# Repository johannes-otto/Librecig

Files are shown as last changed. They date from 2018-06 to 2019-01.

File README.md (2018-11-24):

# Librecig
Want to vape hard? Want to vape free?

## Disclaimer
Neither I nor any of the contributors of this project are reponsible for anything that might happen to you with self build mods. Lithium-Ion batteries are dangerous when handled incorrectly and can seriously harm you. If you build one of these mods, you take the responsibility for yourself. Also I'm not an electrical engineer. My designs work for me, but that doesn't mean that they are safe in any way.

## Please don't sell these designs
All this stuff is released under GPL V3.It should be free for anyone wanting to build his own mod.

## What this is about
I started my first build due to paranoia of the European TPD laws. I have a certain style of vaping and I don't want the government to tell me what to vape and what not.
Also I was annoyed that my favorite mods break after a year or two of constant usage and that I can't buy spare parts to repair them.

Since then building and 3D printing mods has become a passion of mine. I did countless iterations and now I think the designs reached
enough maturity to be released.That doesn't mean that this is the end. I'm constantly improving my designs and from time to time I try something completely new.
The plan is to share everything.
I hope that other modders are willing to contribute, so that we could build a free repository of mods for "Maker-Vapers".

## Available Models

- [Ratte Platform](https://github.com/johannes-otto/Librecig/blob/master/Ratte%20and%20Variations/Readme.md)
  - [Ratte](https://github.com/johannes-otto/Librecig/blob/master/Ratte%20and%20Variations/Ratte/Readme.md)
  - [Leviathan](https://github.com/johannes-otto/Librecig/blob/master/Ratte%20and%20Variations/Leviatan/Readme.md)
  - [Wisent](https://github.com/johannes-otto/Librecig/blob/master/Ratte%20and%20Variations/Wisent/Readme.md)
- [Eichörnchen](https://github.com/johannes-otto/Librecig/blob/master/Eichh%C3%B6rnchen/README.md)

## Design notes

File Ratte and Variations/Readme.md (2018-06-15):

# Ratte Base
The goal with this series of Mods is to build a versatile, easy to assemble mod. It's supposed to be easily printable, even on cheap printers.

Currently this platform offers the following battery configurations:
- 2x 18650 -> [Die Ratte](https://github.com/johannes-otto/Librecig/blob/master/Ratte%20and%20Variations/Ratte/Readme.md)
- 4x 18650 -> [Der Leviathan](https://github.com/johannes-otto/Librecig/blob/master/Ratte%20and%20Variations/Leviatan/Readme.md)
- 6x 18650 ->  [Der Wisent](https://github.com/johannes-otto/Librecig/blob/master/Ratte%20and%20Variations/Wisent/Readme.md)

The Front Panel is variable, too. You can choose between the following electronics:
- BigAl's ANT 6s
- BigAl's iPWM 6s
- A simple VM+Mosfet with a Master switch (If you're on the cheap)

New electronics might be added as I use them. But you can easily redesign a front panel for a specific board. For example a Yihi SX350 works. But you have to keep in mind that regulated boards are boring ;-).

The Side Panel is slideable, although I nearly only squonk, you can choose between the following panels:
- Blank for your Tanks/normal Drippers
- Squonk
- Top-Feed (As with the DripEZ -> The concept works way better than you might think)

## Want to build it?
[Print instructions](https://github.com/johannes-otto/Librecig/blob/master/Ratte%20and%20Variations/doc/instructions/printing.md)

[Build instructions](https://github.com/johannes-otto/Librecig/blob/master/Ratte%20and%20Variations/doc/instructions/building.md)

[Usage instructions](https://github.com/johannes-otto/Librecig/blob/master/Ratte%20and%20Variations/doc/instructions/usage.md)

[Back to main](https://github.com/johannes-otto/Librecig/blob/master/README.md)


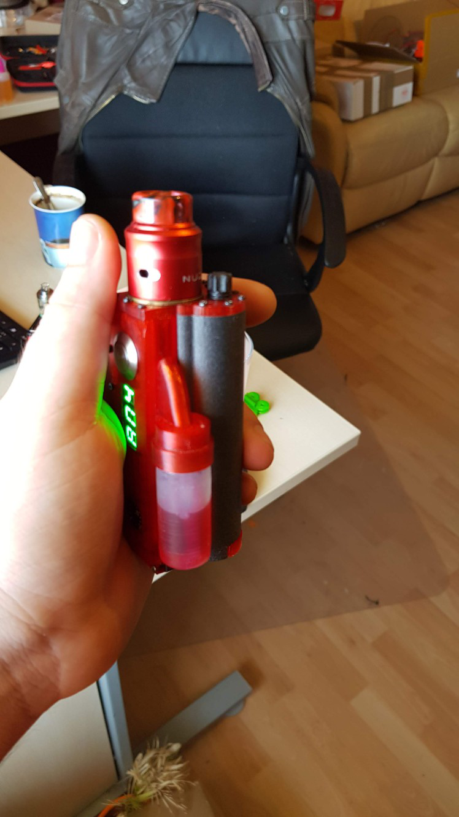
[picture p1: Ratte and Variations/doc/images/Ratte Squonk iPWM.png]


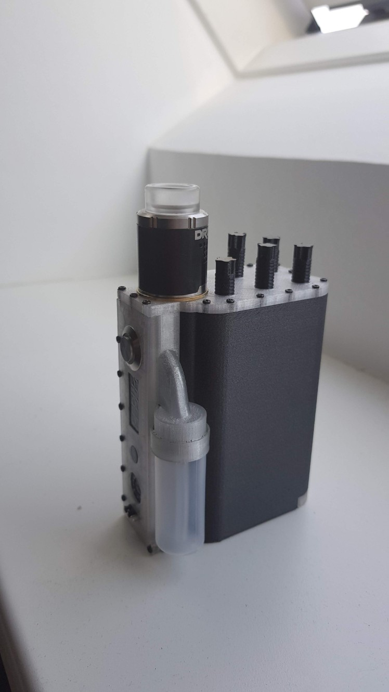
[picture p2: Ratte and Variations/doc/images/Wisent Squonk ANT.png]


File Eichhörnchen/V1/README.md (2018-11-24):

# Eichörnchen
This mod is a redesign from scratch based on the ideas and experiences of "die Ratte". The mod is pretty compact and uses 21700s. 
The exchangeable side panels have been dropped since I found myself squonking all the time anyway. I might design a non-squonk variation
at some point if I come across a tank that really blows me away.
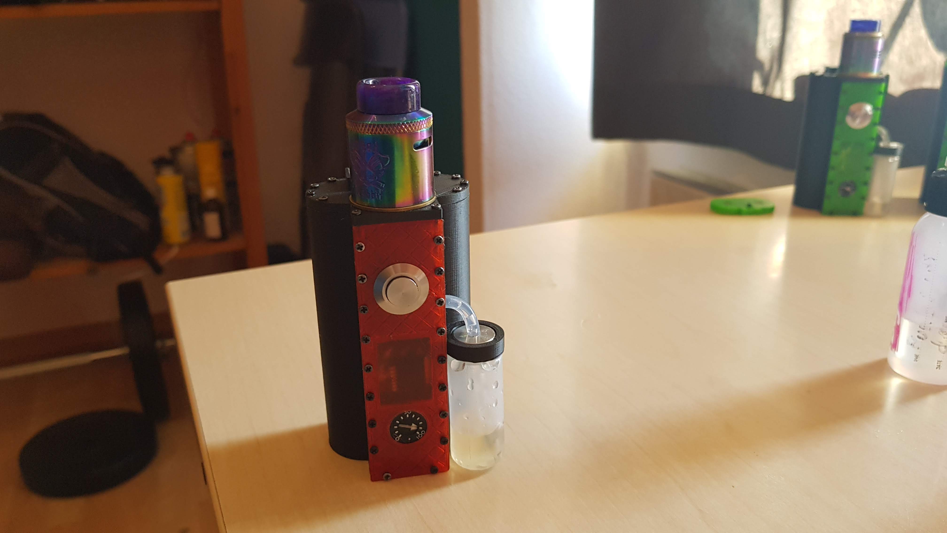
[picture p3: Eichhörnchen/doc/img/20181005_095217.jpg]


## Parts you need
- Obviously the printed parts. I recommend to use PETG
- 25mm Squonk 510 ([MM150](http://www.modmaker.co.uk/Mod-Making-Supplies/Squonk-Parts/MM510-Squonker-Connector))
- [BigAls iPWM](http://www.bigalsmods.com/Big-Als-Intelligent-PWM-iPWM-2s-6s-wpot_p_12.html)
- Squonk bottle, the design is made for the squonk bottle by [ModMaker](http://www.modmaker.co.uk/Mod-Making-Supplies/Squonk-Parts/MM-Squonker-Bottle-Kit). You can use others, but the mod is designed to fit this. If you want to use another, open an issue here and I will alter the design for you.
- Some extra tubing - about 5cm from the top of the bottle to the 510
- Mitec Switch 12mm
- 0.28" Voltmeter
- 2x M3 screws with nuts for the bottom contact bridge
- A piece of brass or copper for the bottom contact bridge
- Tiny Screws I use [Din 1.5x6](https://minischrauben.com/blech-holzschrauben-linsenkopf--44900.html). You can use others. The holes are 1.5mm x 6mm
- [Keystone 209](http://www.modmaker.co.uk/Keystone-209-Battery-Contact-Clips-x-4?search=keystone) Clips for the top contacts

## Tips and Tricks
- Put a strip of Tesa on the top of the voltmeter. It acts as a screen protector and helps to seal it.
- Cut down the legs of the switch. They don't need to be that long and may contact the 510 otherwise.
- Wait for the glue to be really dry ;-)
- Don't use overly thick cables, you don't have much extra space. I use 1.5mm²
- Don't use too long cables or it might not fit

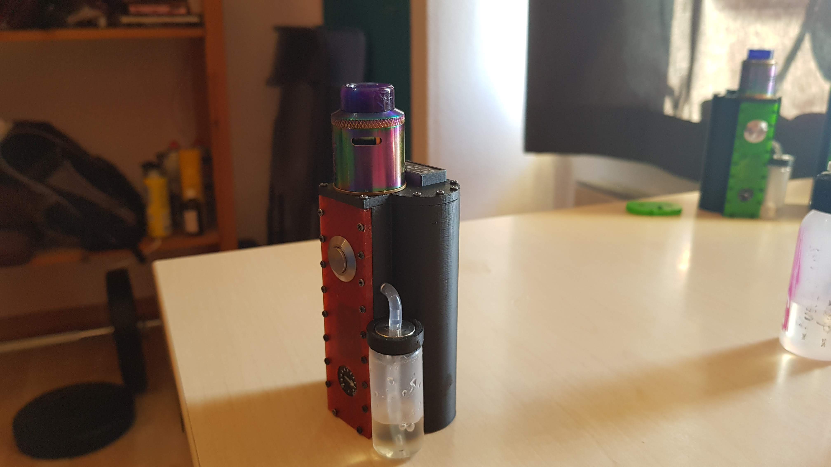
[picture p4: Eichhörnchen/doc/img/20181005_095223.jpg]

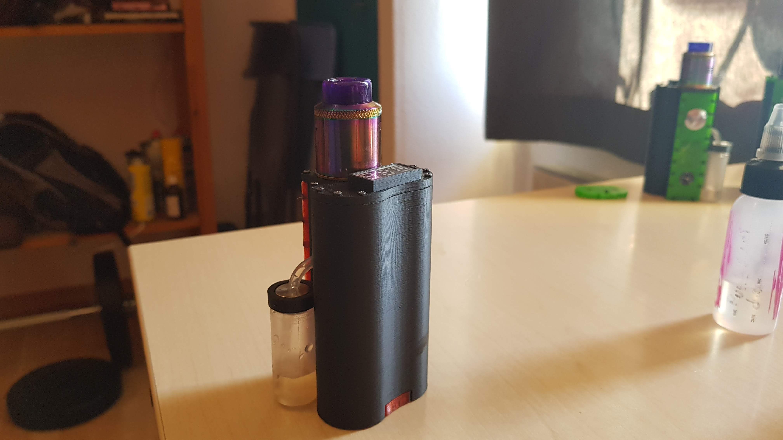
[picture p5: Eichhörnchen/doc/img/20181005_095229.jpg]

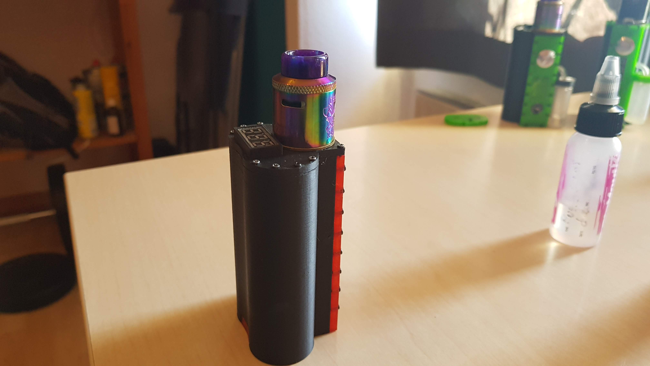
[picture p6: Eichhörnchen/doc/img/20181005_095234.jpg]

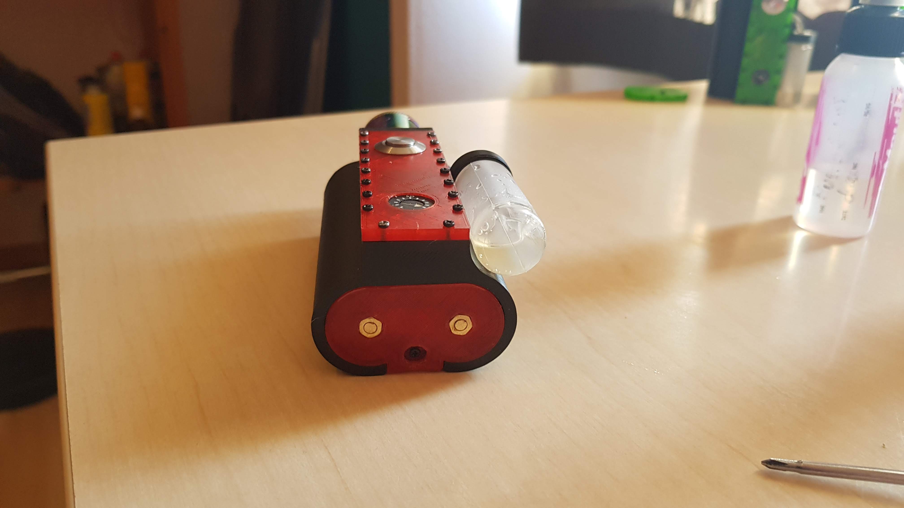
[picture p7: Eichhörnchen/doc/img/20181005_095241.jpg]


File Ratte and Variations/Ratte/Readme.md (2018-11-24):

# Die Ratte
This is a dual 18650 Mod. It's not too big, has enough battery life for a day and hits good.

[build instructions](https://github.com/johannes-otto/Librecig/blob/master/Ratte%20and%20Variations/doc/instructions/building.md)



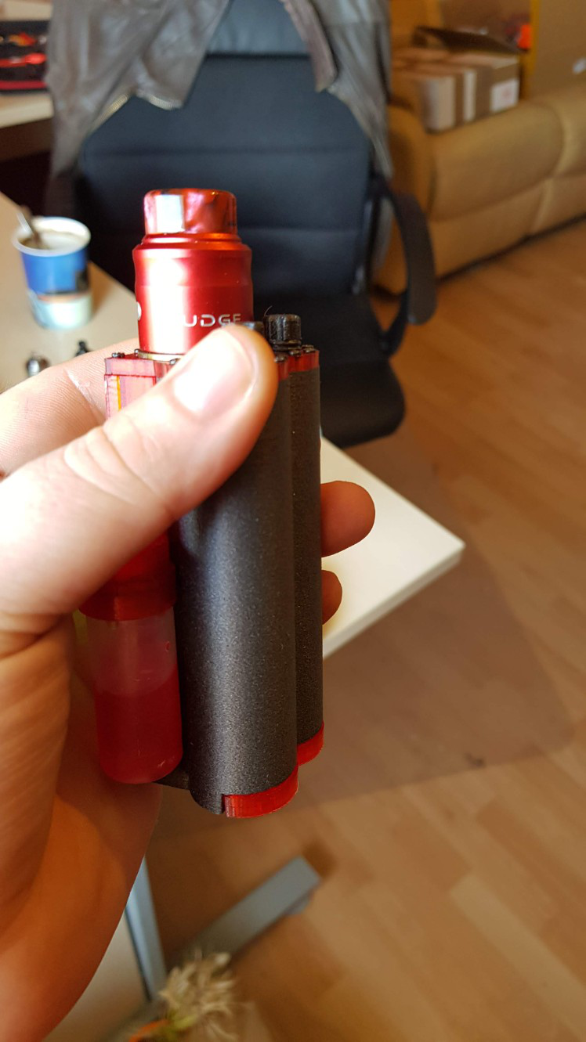
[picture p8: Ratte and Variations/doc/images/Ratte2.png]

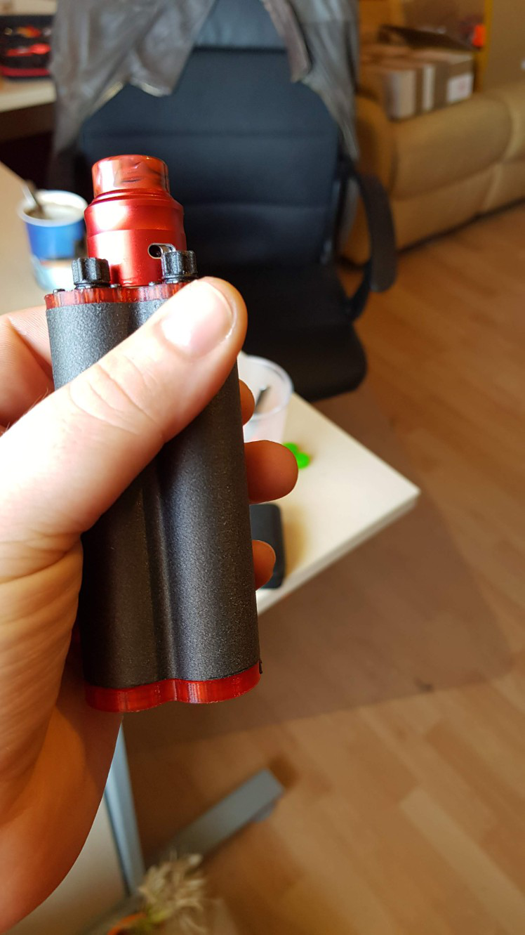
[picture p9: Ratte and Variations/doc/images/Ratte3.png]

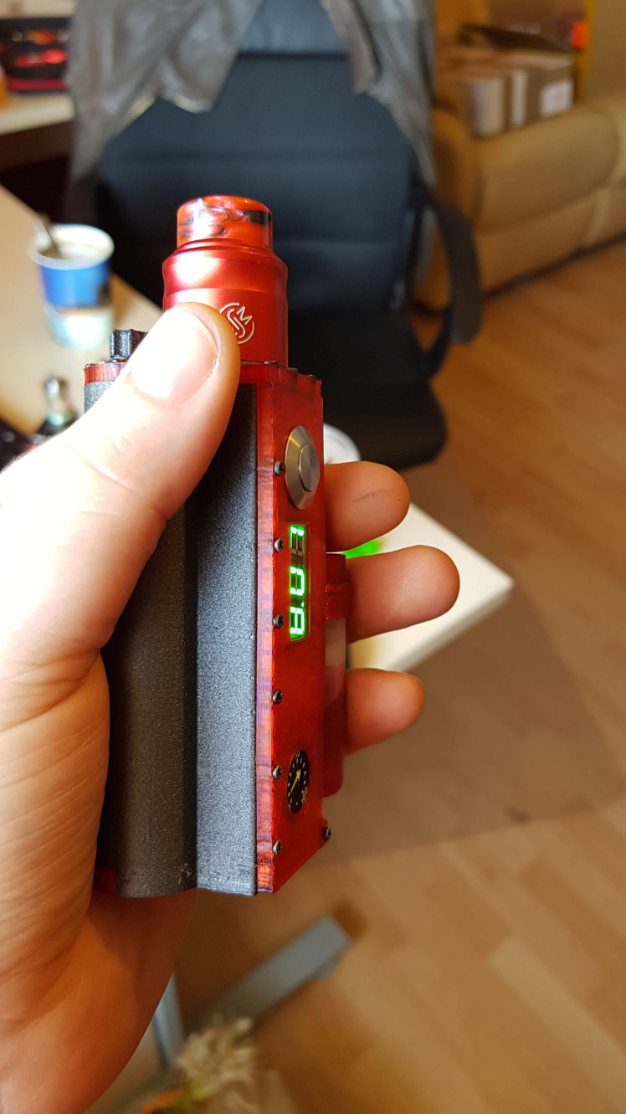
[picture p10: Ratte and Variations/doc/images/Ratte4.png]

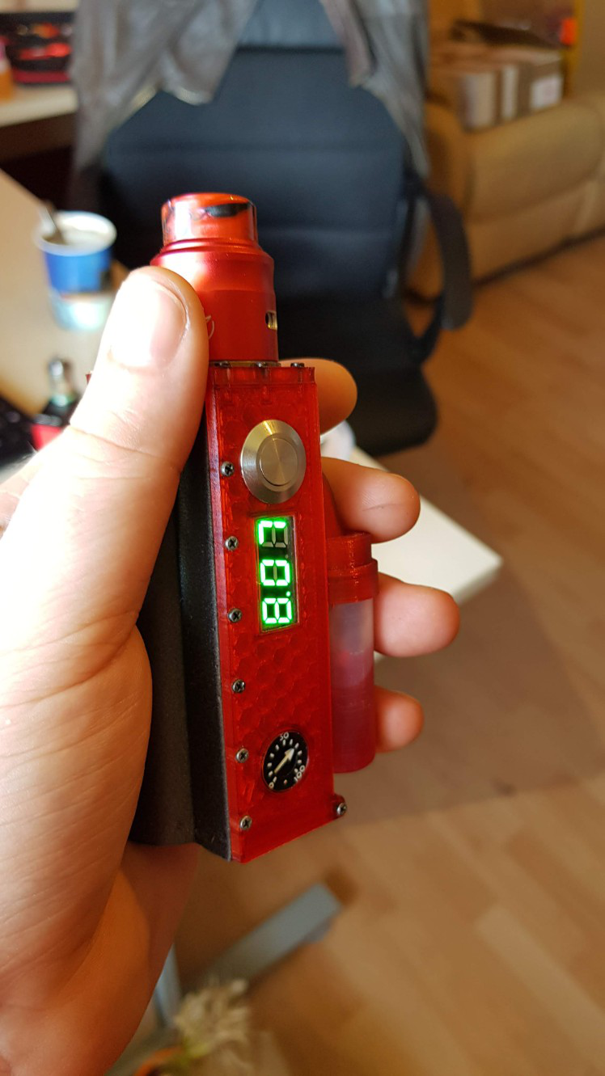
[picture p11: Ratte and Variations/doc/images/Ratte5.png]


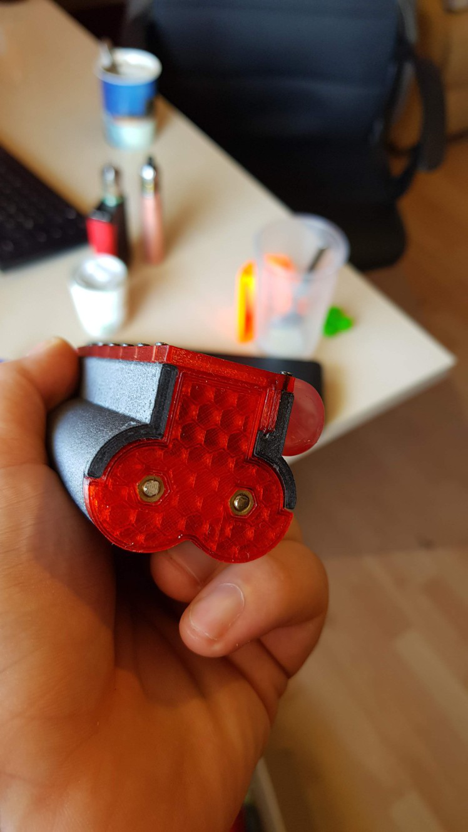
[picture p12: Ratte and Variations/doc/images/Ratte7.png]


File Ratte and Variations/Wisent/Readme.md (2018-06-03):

# Der Wisent
This mod is just dangerous. You should not build it if you don't know what you're doing or if you care about your wellbeeing.

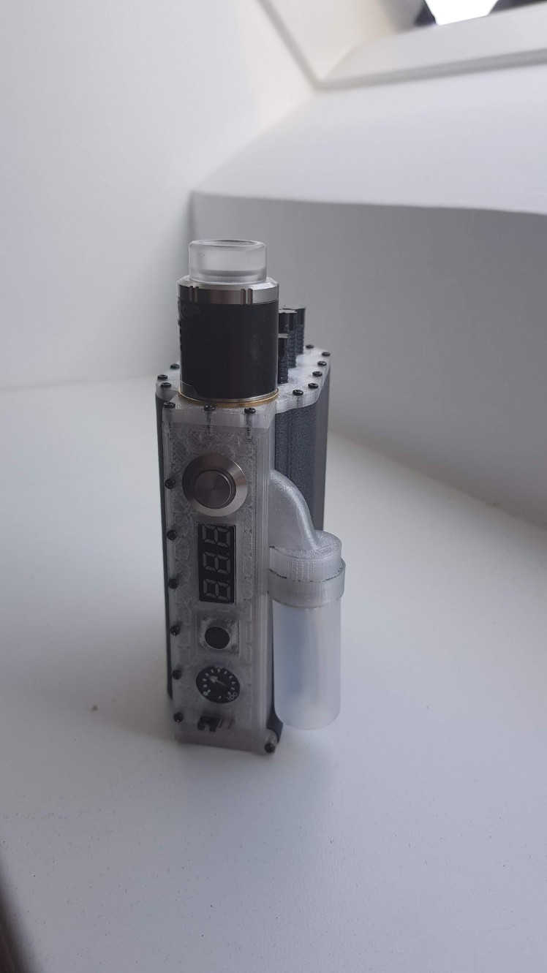
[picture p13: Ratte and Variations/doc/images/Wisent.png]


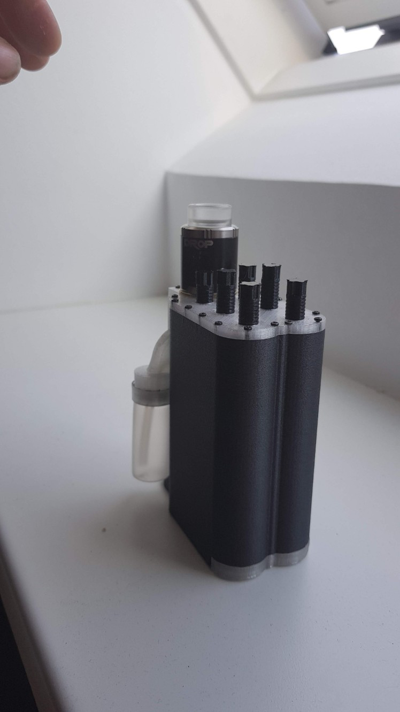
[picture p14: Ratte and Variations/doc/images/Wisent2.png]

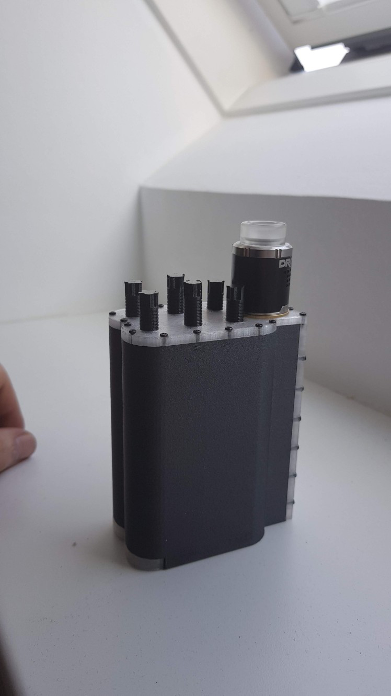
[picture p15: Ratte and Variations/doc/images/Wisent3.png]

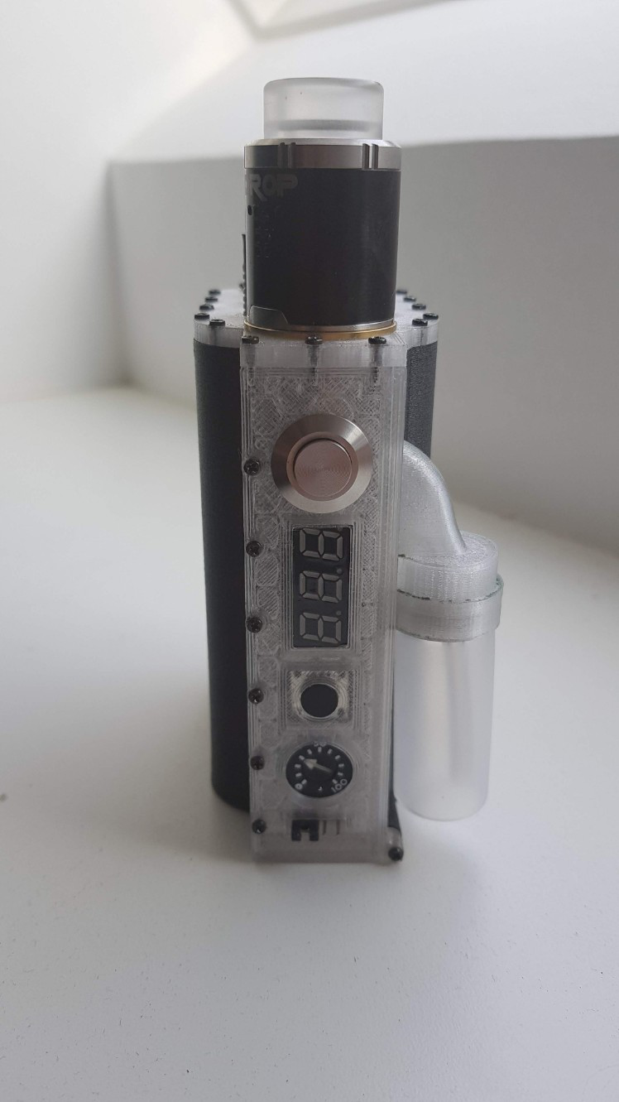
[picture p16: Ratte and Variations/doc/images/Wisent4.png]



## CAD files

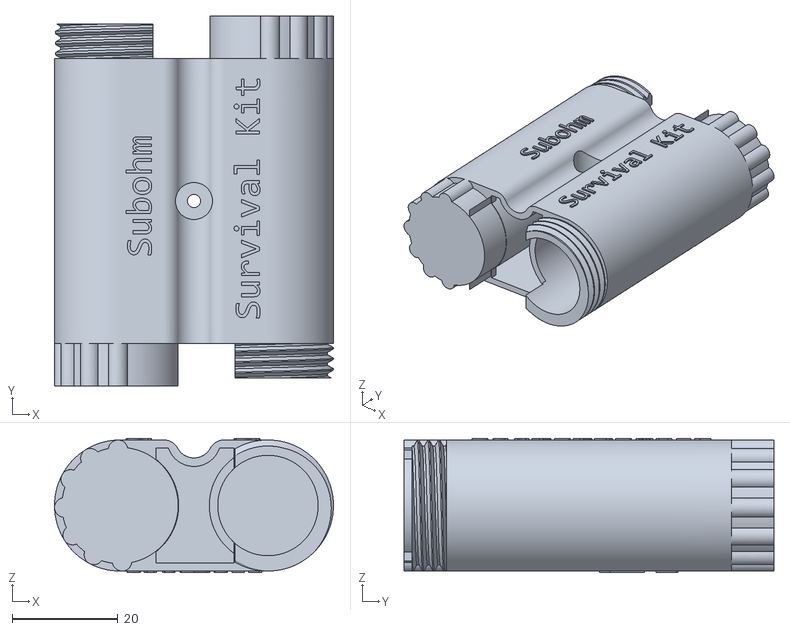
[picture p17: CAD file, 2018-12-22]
Battery Compartments/Jonny Drips Subohm Survival Kit/Subohm Survival Kit v4_Subohm Survival Kit v4_body_Subohm Survival Kit v4.stl
52.8 x 70.0 x 25.4

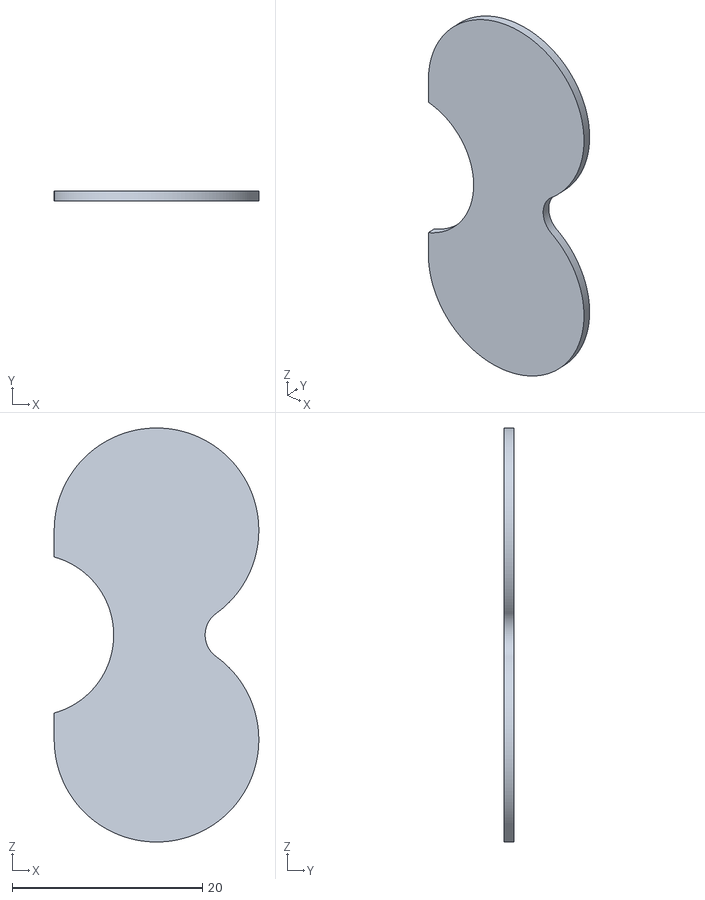
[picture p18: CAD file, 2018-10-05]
Eichhörnchen/V1/insulator.stl
21.5 x 1.00 x 43.5

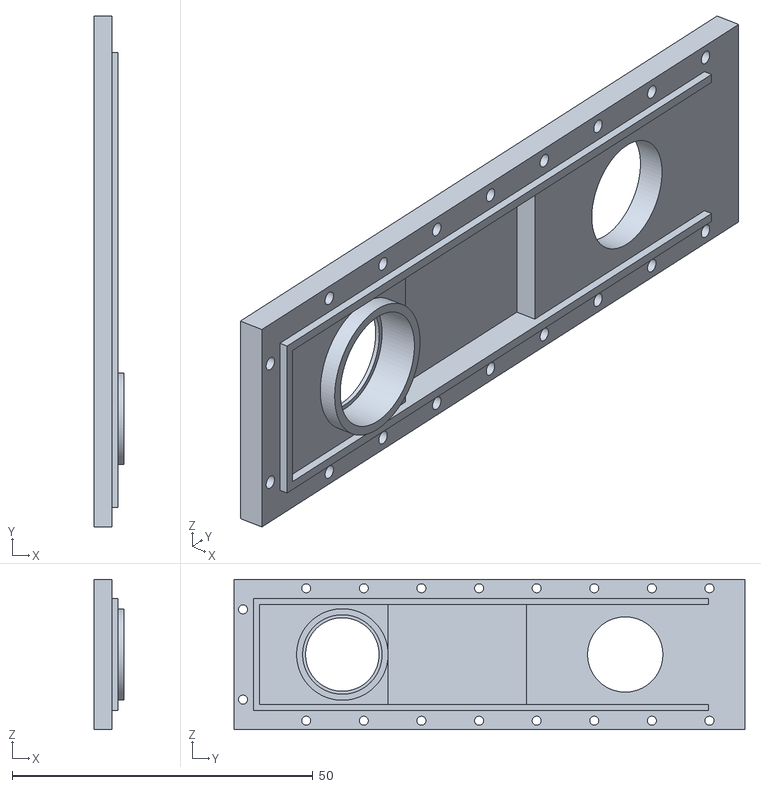
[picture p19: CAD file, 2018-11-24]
Eichhörnchen/V2 No Squonk/front.stl
5.00 x 84.9 x 25.0

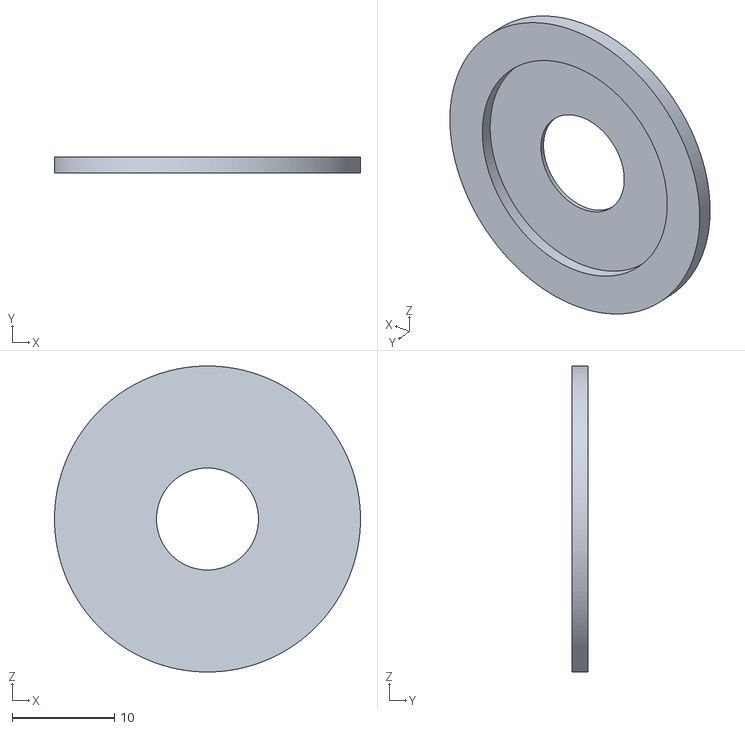
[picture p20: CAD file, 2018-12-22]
Großwiesel/Großwiesel v7_Großwiesel v7_22mm to 25mm adapter_Großwiesel v7.stl
30.0 x 1.60 x 30.0

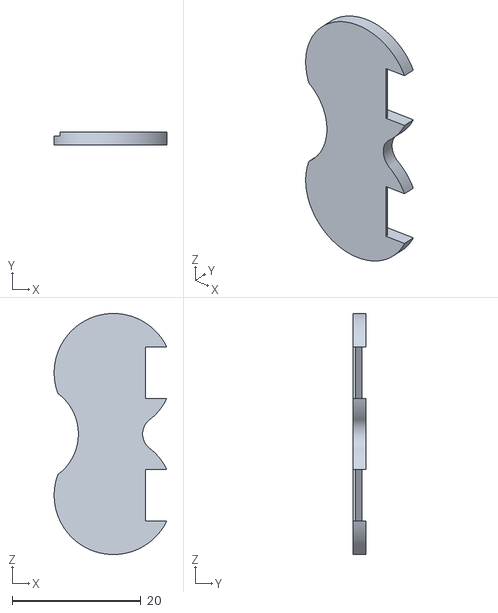
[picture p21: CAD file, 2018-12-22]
Großwiesel/v7/Großwiesel v7_Großwiesel v7_terminal_Großwiesel v7.stl
17.5 x 2.00 x 37.4

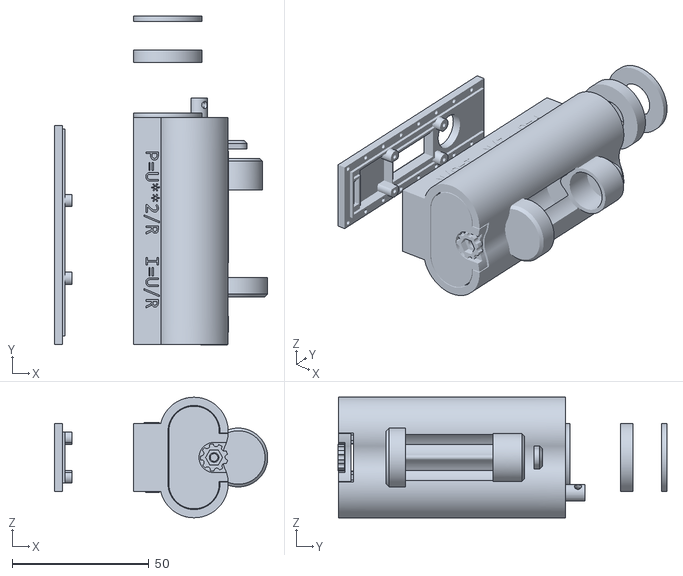
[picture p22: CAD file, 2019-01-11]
Otter/Otter v10.stl
77.9 x 120.1 x 44.0

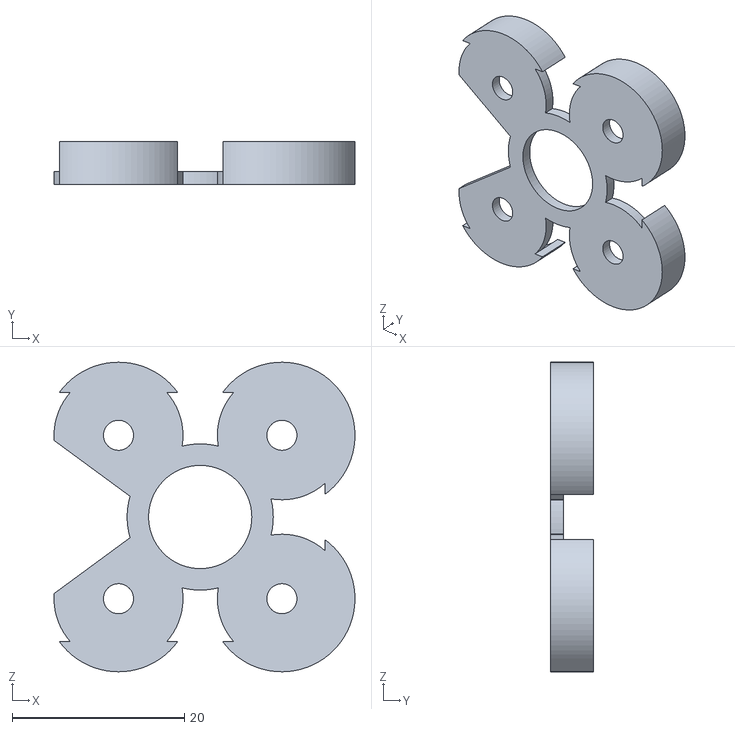
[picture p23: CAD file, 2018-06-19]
Ratte and Variations/Leviatan/Leviathan Top Pole Cover.stl
35.0 x 5.00 x 36.0

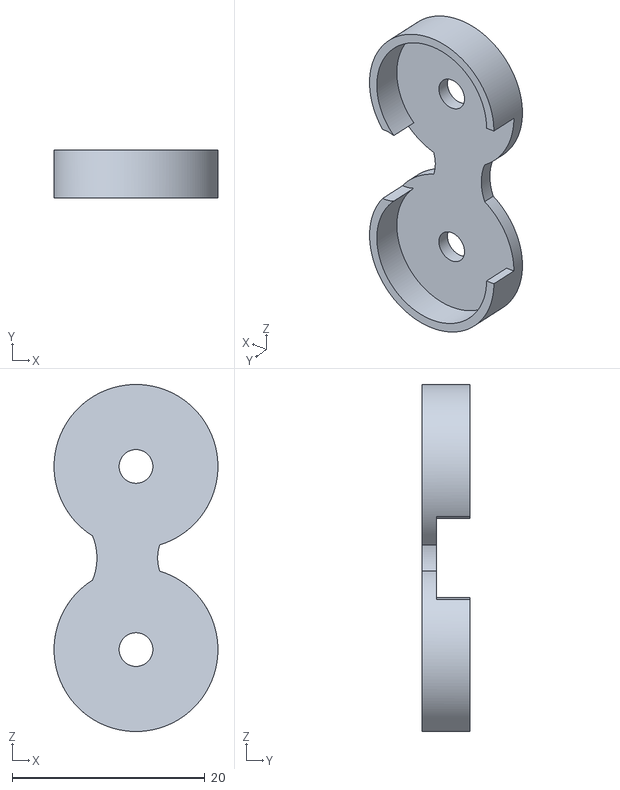
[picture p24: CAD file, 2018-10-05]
Ratte and Variations/Ratte/Ratte Top Pole Cover.stl
17.0 x 5.00 x 36.0

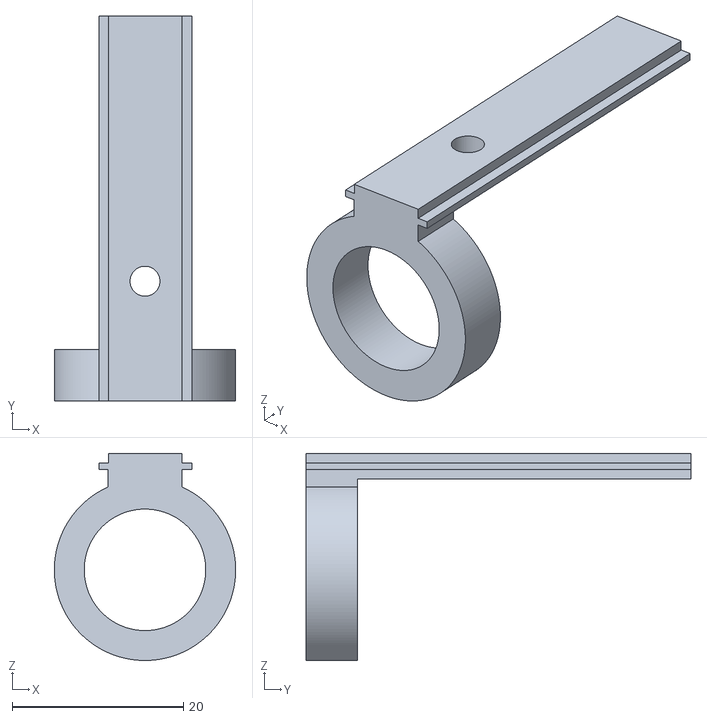
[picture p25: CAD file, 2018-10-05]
Ratte and Variations/shared parts/New Squonk Side Panel 1.stl
21.2 x 45.0 x 24.2

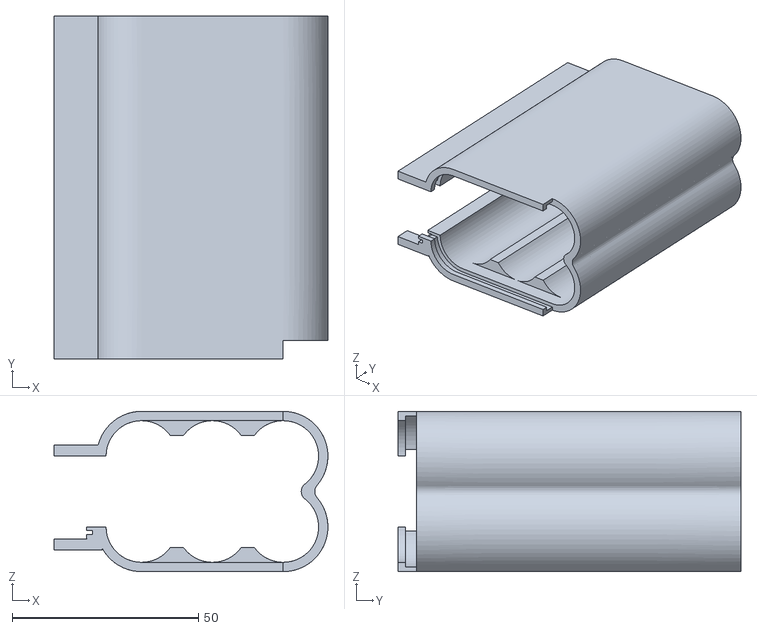
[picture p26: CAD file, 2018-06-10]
Ratte and Variations/Wisent/Wisent Body.stl
73.5 x 92.0 x 43.0

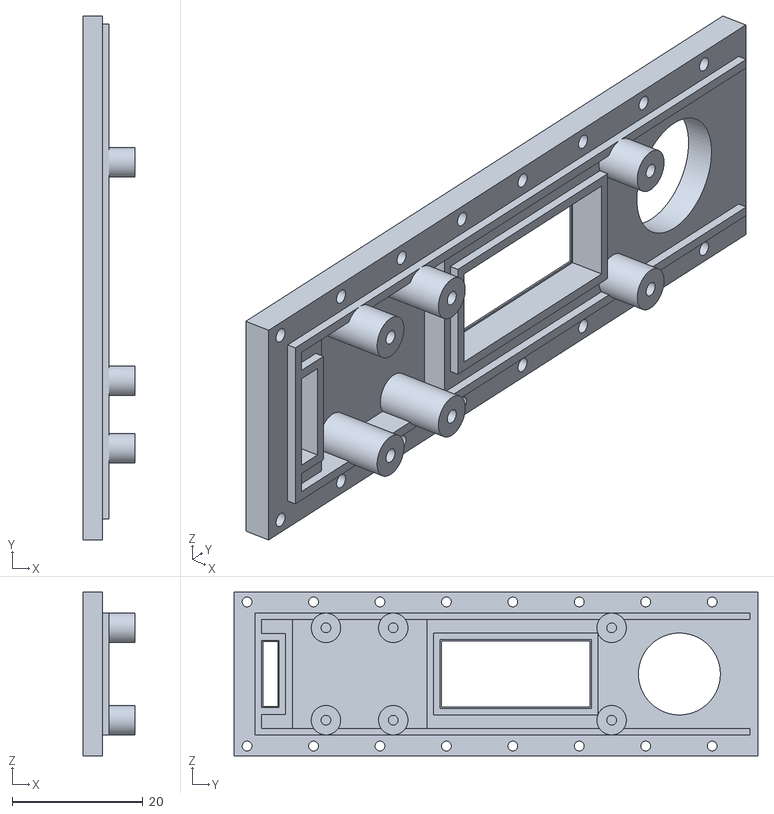
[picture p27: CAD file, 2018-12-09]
Wiesel/alternative Front parts/front_mosfet.stl
8.00 x 80.0 x 25.0

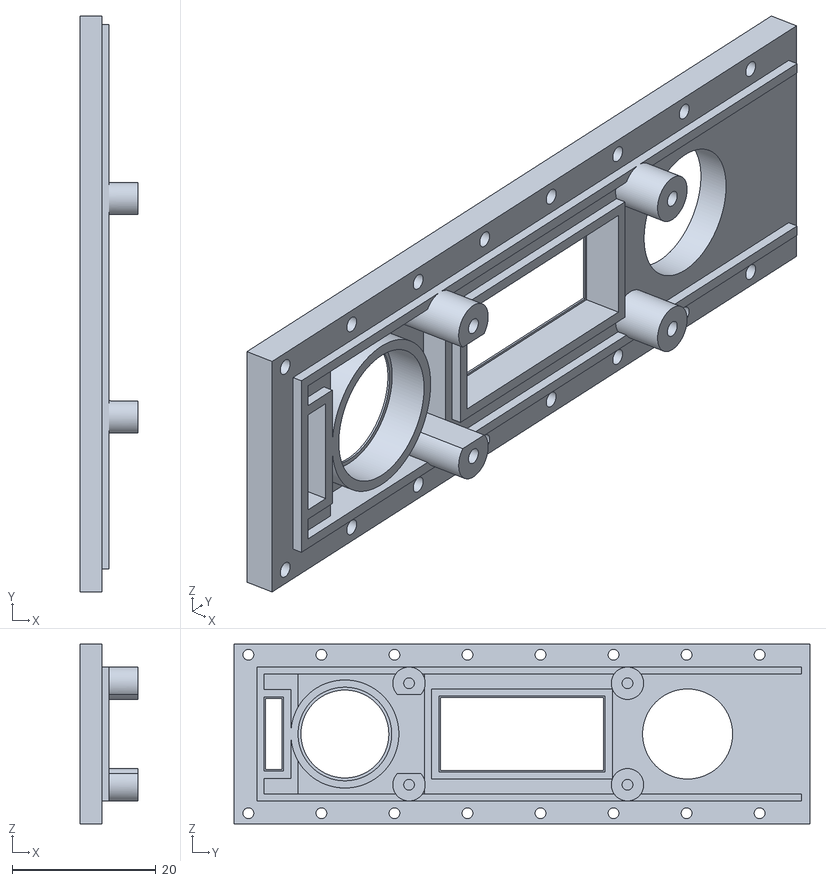
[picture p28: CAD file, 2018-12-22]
Wiesel/v4/Wiesel2 v4_Wiesel2 v4_front_Wiesel2 v4.stl
8.00 x 80.0 x 25.0

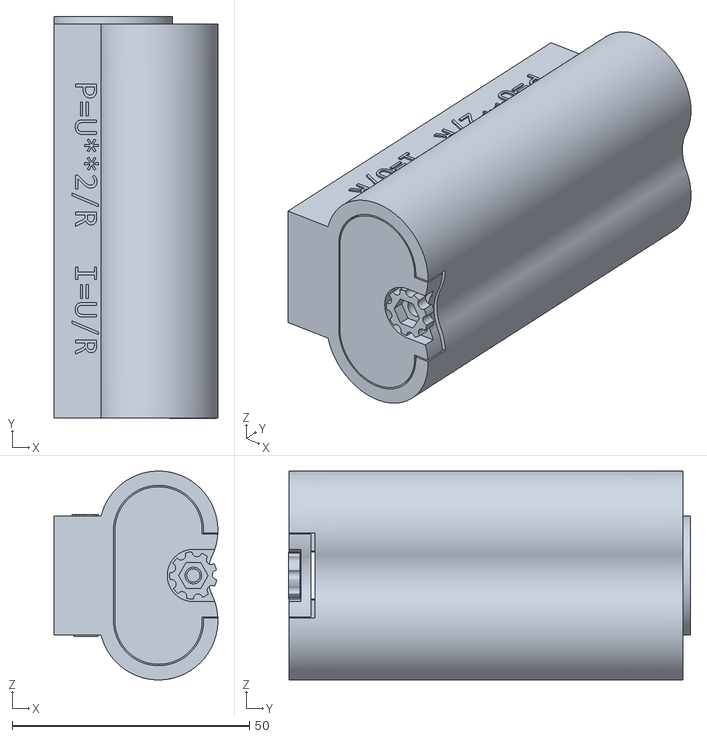
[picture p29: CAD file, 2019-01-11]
Wiesel/Wiesel2 v4.stl
34.5 x 84.7 x 44.0

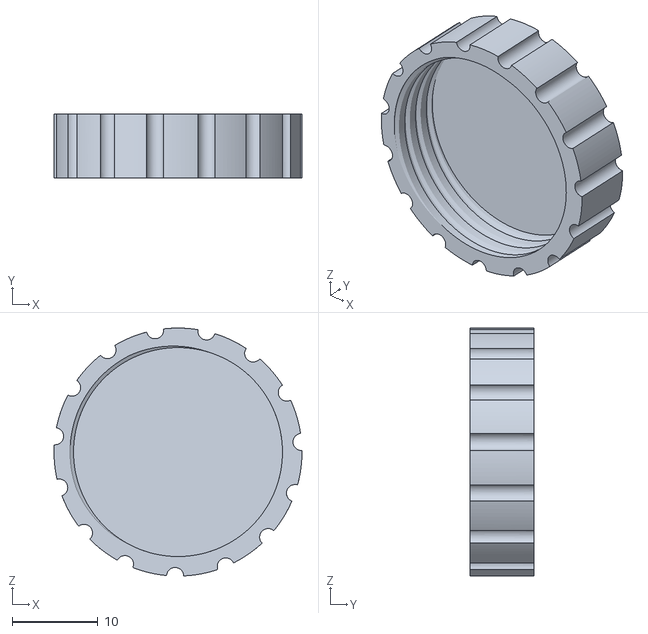
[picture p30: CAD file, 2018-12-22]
Battery Compartments/Jonny Drips Subohm Survival Kit/Subohm Survival Kit v4_Subohm Survival Kit v4_Deckel _Subohm Survival Kit v4.stl
29.0 x 7.50 x 29.0

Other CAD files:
Eichhörnchen/V2 No Squonk/insulator.stl
Großwiesel/Großwiesel v7_Großwiesel v7_body_Großwiesel v7.stl
Großwiesel/v7/Großwiesel v7_Großwiesel v7_top_Großwiesel v7.stl
Battery Compartments/Jonny Drips Subohm Survival Kit/Subohm Survival Kit v4_Subohm Survival Kit v4_Insert_Subohm Survival Kit v4.stl
Eichhörnchen/V1/battery door.stl
Eichhörnchen/V1/beautylip.stl
Eichhörnchen/V1/body.stl
Eichhörnchen/V1/front.stl
Eichhörnchen/V1/terminal.stl
Eichhörnchen/V1/top.stl
Eichhörnchen/V2 No Squonk/battery door.stl
Eichhörnchen/V2 No Squonk/beautylip.stl
Eichhörnchen/V2 No Squonk/body.stl
Eichhörnchen/V2 No Squonk/front mosfet.stl
Eichhörnchen/V2 No Squonk/front_mosfet.stl
Eichhörnchen/V2 No Squonk/terminal.stl
Eichhörnchen/V2 No Squonk/top.stl
Eichhörnchen/battery door.stl
Eichhörnchen/body.stl
Großwiesel/Großwiesel v7_Großwiesel v7_battery door_Großwiesel v7.stl
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

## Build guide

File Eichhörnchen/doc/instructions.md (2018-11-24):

# Build Instructions - "Das Eichhörnchen"

## Warning and intentions
This document should help you to put together this mod. However, this may just serve as a documentary how I do it. I'm not a trained electrician or have any professional authority in this buisiness. If you build your mod, you take the responsibility for it. Things that might happen to electronic cigarettes when misused or improperly assembled:
- Explosions
- Fire
- unhealthy Smoke
- Kittens may die
If you are unsure about electronics or building mods, you shouldn't continue.
I don't provide wiring diagrams. Get them from the manufacturer of your board.

## Again! Lithium-Ion Batterys are little bombs that wait to explode due to improper treatment!!

## Parts you need
- Obviously the printed parts. PETG works fine for me.
- 25mm Squonk 510 ([MM150](http://www.modmaker.co.uk/Mod-Making-Supplies/Squonk-Parts/MM510-Squonker-Connector))
- [BigAls iPWM](http://www.bigalsmods.com/Big-Als-Intelligent-PWM-iPWM-2s-6s-wpot_p_12.html)
- Squonk bottle, the design is made for the squonk bottle by [ModMaker](http://www.modmaker.co.uk/Mod-Making-Supplies/Squonk-Parts/MM-Squonker-Bottle-Kit). Alternatively there is a silicone bottle available by [ModMaker](http://www.modmaker.co.uk/Mod-Making-Supplies/Squonk-Parts/MM-Dinky-Silicone-Squonker-Bottle-Kit-Light). You can use others, but the mod is designed to fit this. If you want to use another, open an issue here and I will alter the design for you.
- Some extra tubing - about 5cm from the top of the bottle to the 510
- Mitec Switch 12mm
- 0.28" Voltmeter
- 2x M3 screws with nuts for the bottom contact bridge
- A piece of brass or copper for the bottom contact bridge
- 30x Tiny Screws. I use [Din 1.5x6](https://minischrauben.com/blech-holzschrauben-linsenkopf--44900.html). You can use others. The holes are 1.5mm x 6mm
- [Keystone 209](http://www.modmaker.co.uk/Keystone-209-Battery-Contact-Clips-x-4?search=keystone) Clips for the top contacts

## Build Process

Start by inspecting the printed parts. The parts should fit together nicely and there shouldn't be gaps.
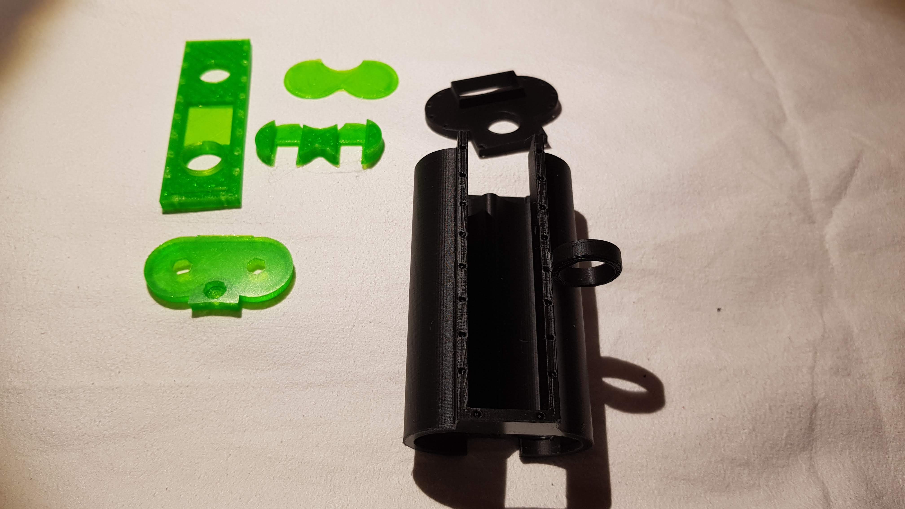
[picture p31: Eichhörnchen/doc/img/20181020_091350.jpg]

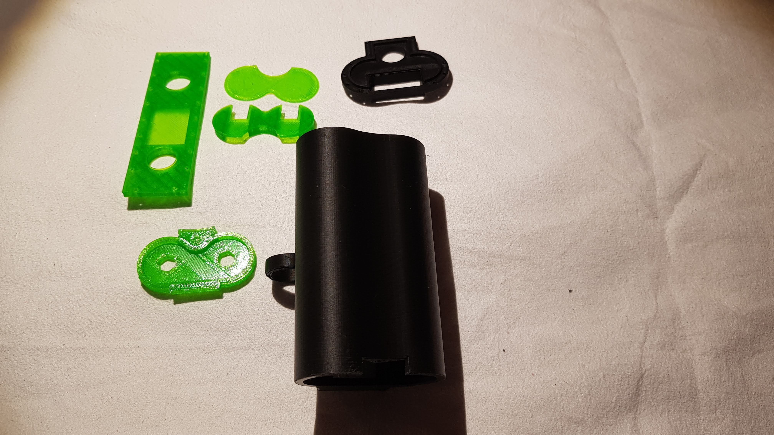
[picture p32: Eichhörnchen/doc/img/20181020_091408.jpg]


Put two strips of TESA on the display of your Voltmeter to protect it from liquid damage
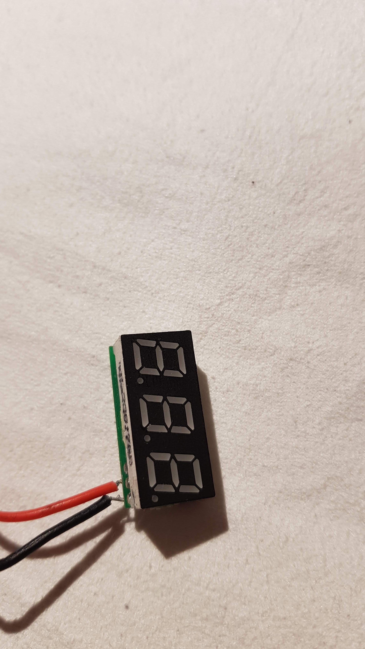
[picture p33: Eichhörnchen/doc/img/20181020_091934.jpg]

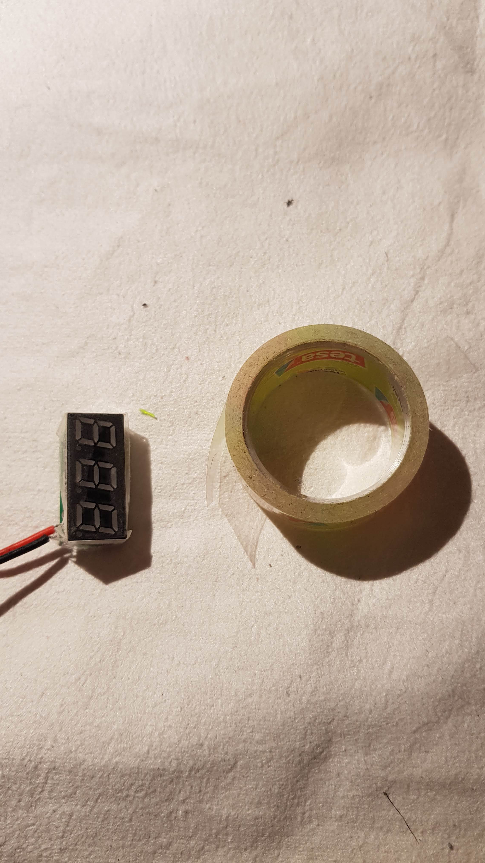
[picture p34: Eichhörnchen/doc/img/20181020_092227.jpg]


Then glue it into the top part. Make sure it sits really well. You can't correct it later on. Also don't use excessive amounts of glue.
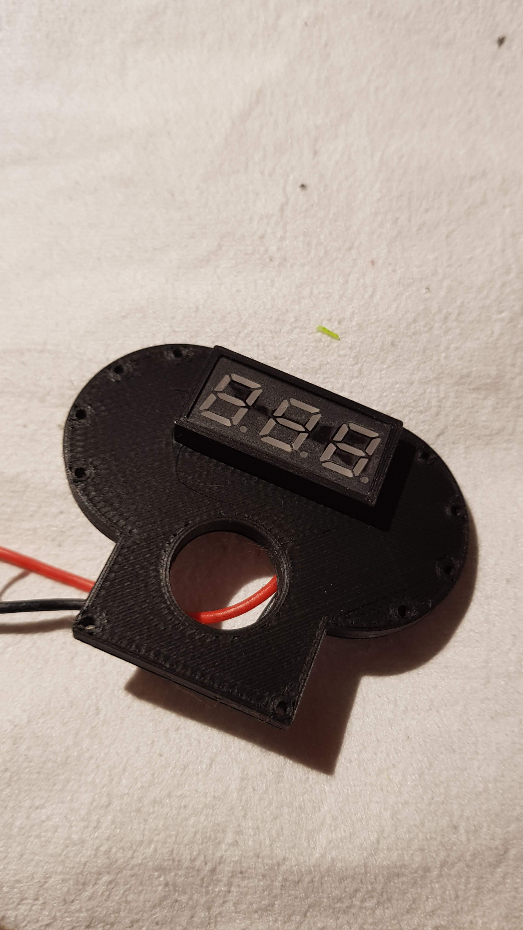
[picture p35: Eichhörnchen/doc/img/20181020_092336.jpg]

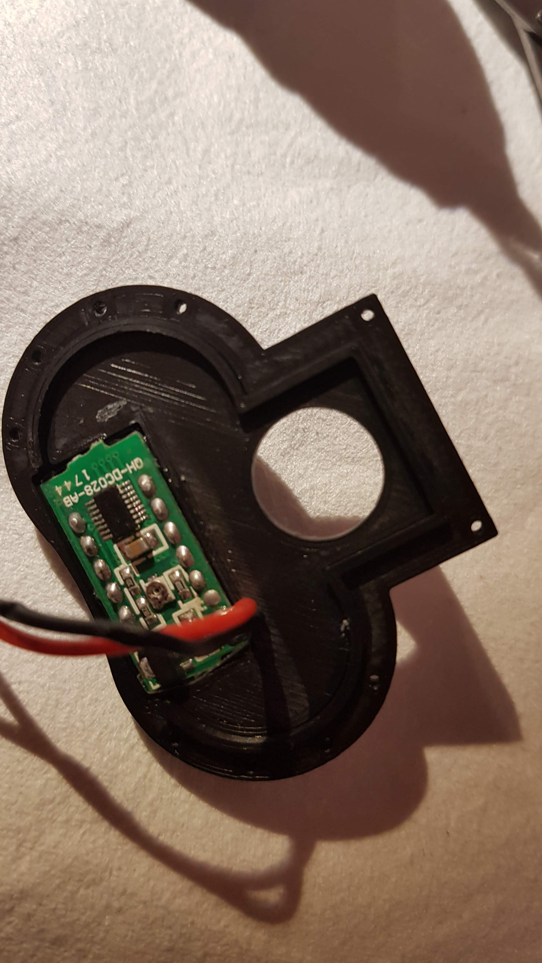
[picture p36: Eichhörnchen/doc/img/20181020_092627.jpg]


Screw the Mitec switch into the front panel. Make sure it sits tight. If the Nut comes loose inside your mod, it might short out. Also cut down the leads of the switch and put some solder on it.
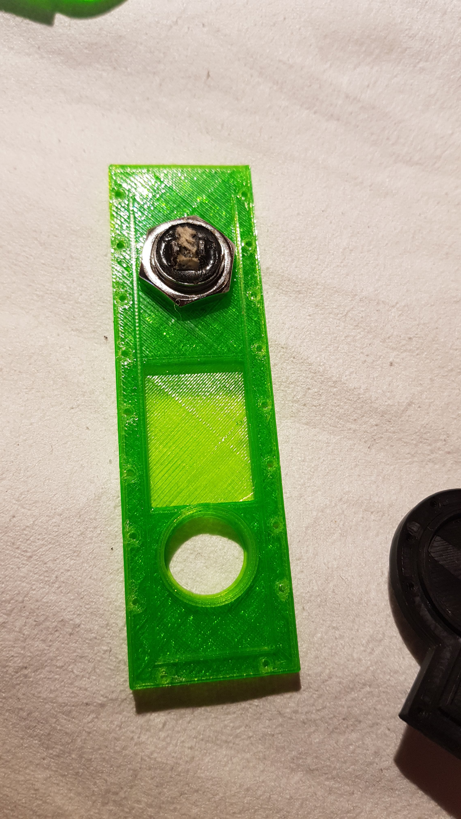
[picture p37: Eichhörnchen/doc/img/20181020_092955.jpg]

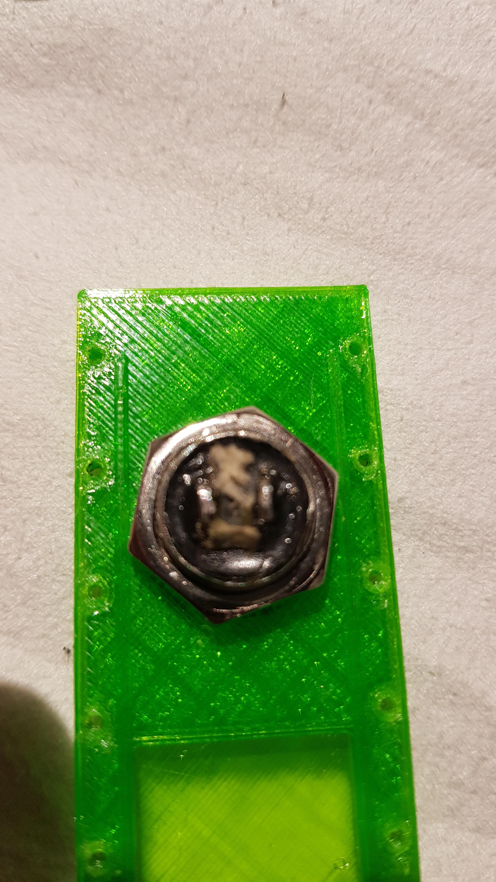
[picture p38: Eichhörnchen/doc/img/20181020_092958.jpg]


Glue the pot with the board into the front panel. Make sure it sits correct and flush. 
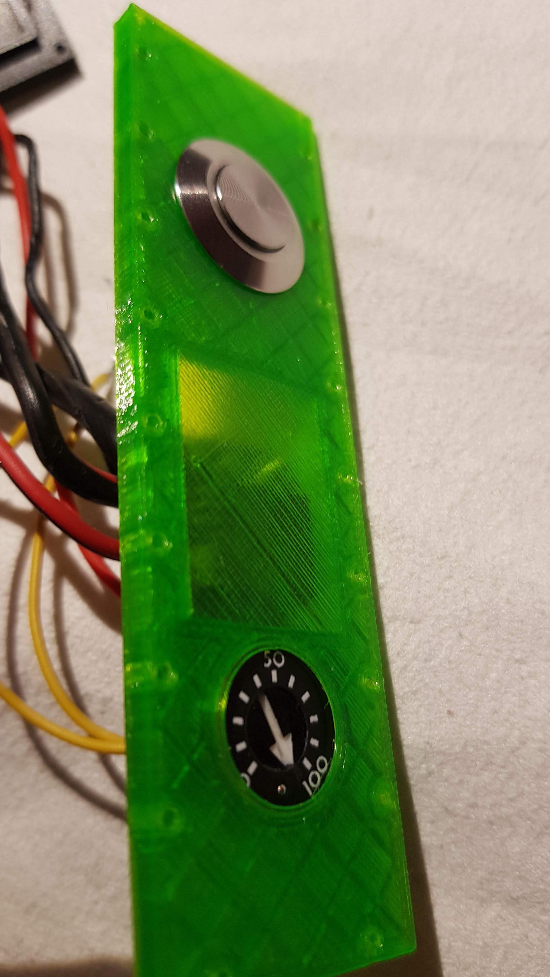
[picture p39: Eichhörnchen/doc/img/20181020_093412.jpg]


!!Be sure to let the glue dry completely before continuing. Otherwise the board and the voltmeter might move during assembly!!

Prepare the battery door. In this case the bridge looks really janky and wrong, cause I recycled a piece I had lying arround. The correct way is:
- Drill 2 holes into a piece of brass/copper. The holes should be 22mm apart. You might use the holes in the battery door as template.
- Cut the acess metal, so the bridge fits inside the battery door.
- Put the M3 nuts into the holes and screw in the bridge.
- Cut or file down the screws so that they don't stick out of the bottom
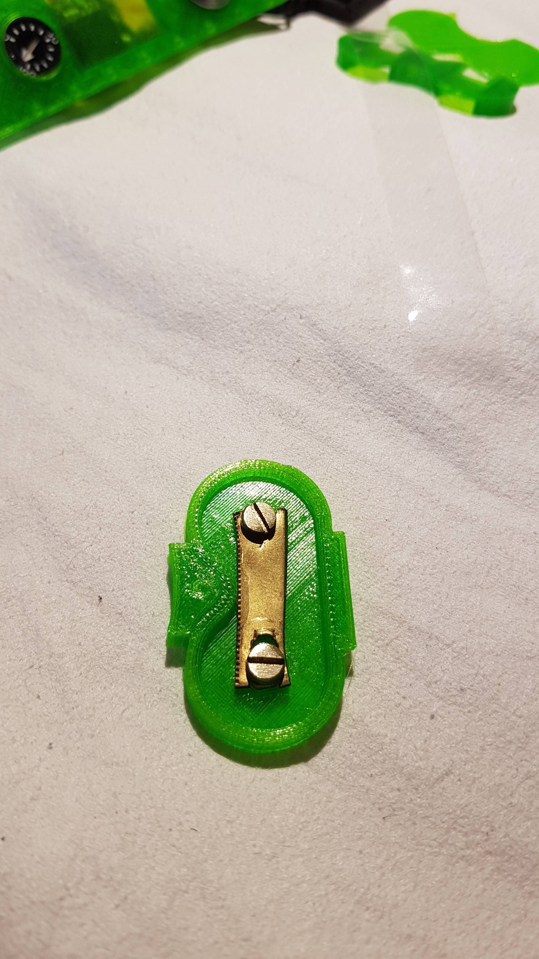
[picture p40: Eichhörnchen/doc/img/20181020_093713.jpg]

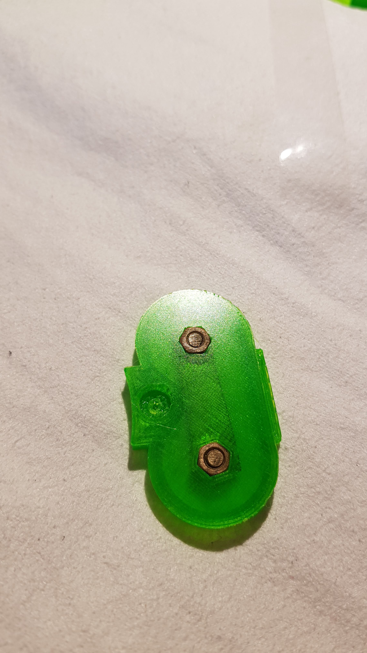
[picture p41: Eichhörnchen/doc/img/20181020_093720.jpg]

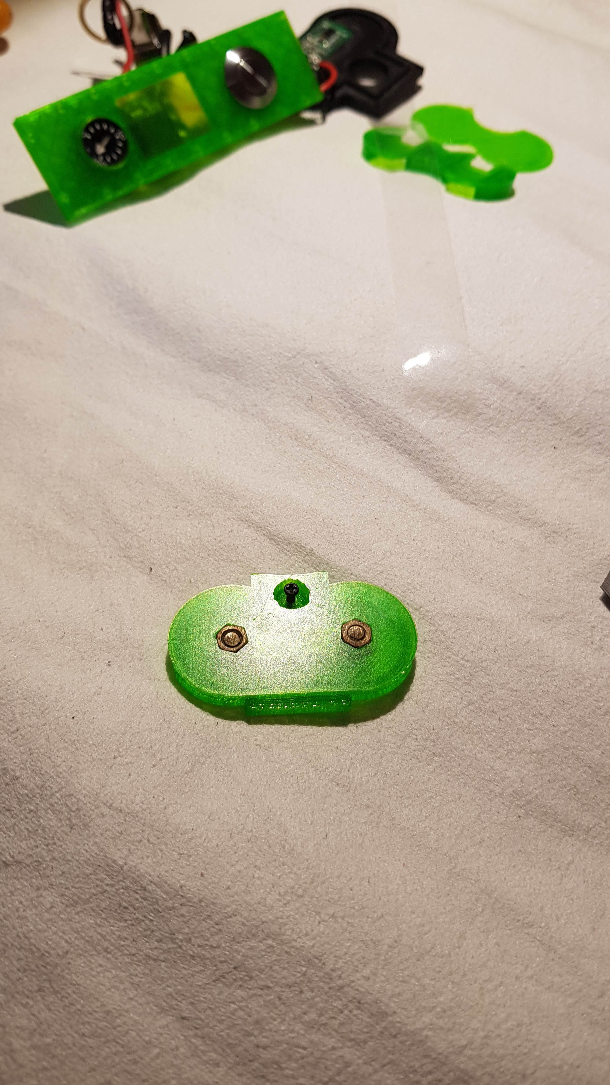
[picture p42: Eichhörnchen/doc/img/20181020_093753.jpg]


Glue the squonk bottle into the body. There are 2 ways since the lid of both bottles is different
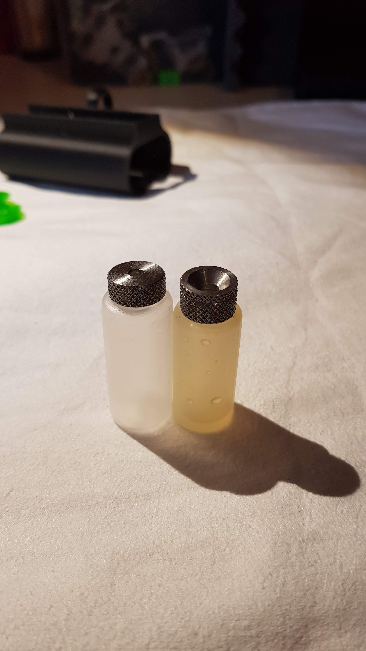
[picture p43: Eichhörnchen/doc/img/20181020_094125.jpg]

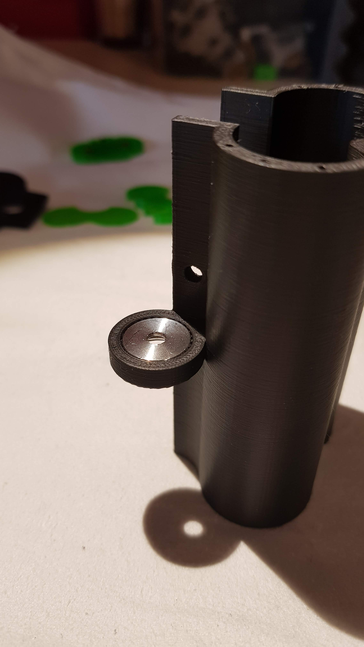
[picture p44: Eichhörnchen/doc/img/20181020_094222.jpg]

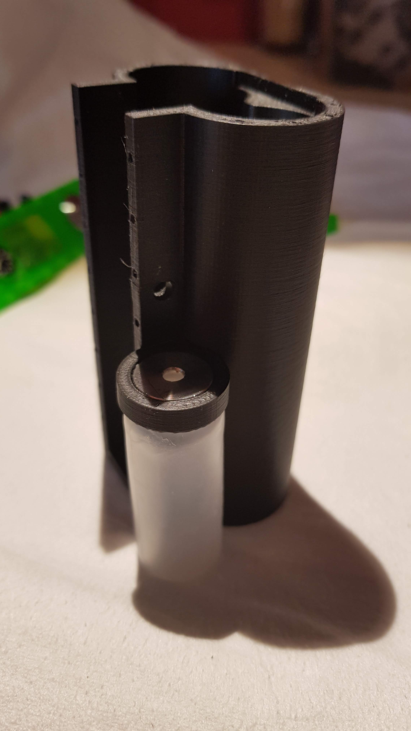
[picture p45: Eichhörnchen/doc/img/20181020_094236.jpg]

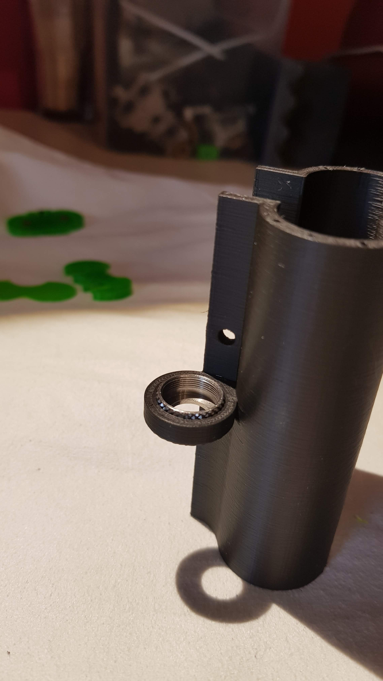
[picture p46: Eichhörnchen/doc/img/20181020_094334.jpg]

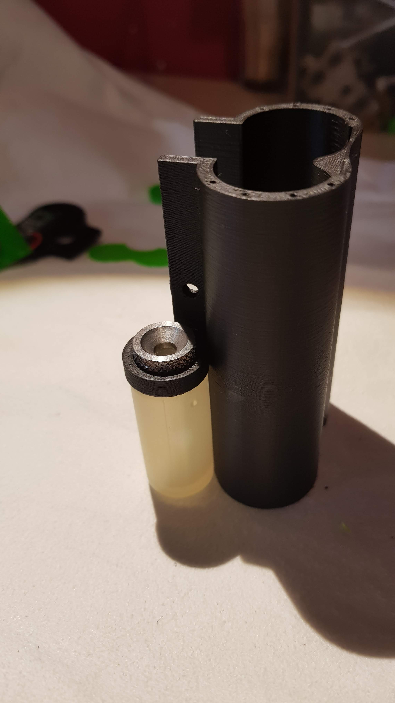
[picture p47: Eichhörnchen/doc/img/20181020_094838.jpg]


Solder the switch to your board
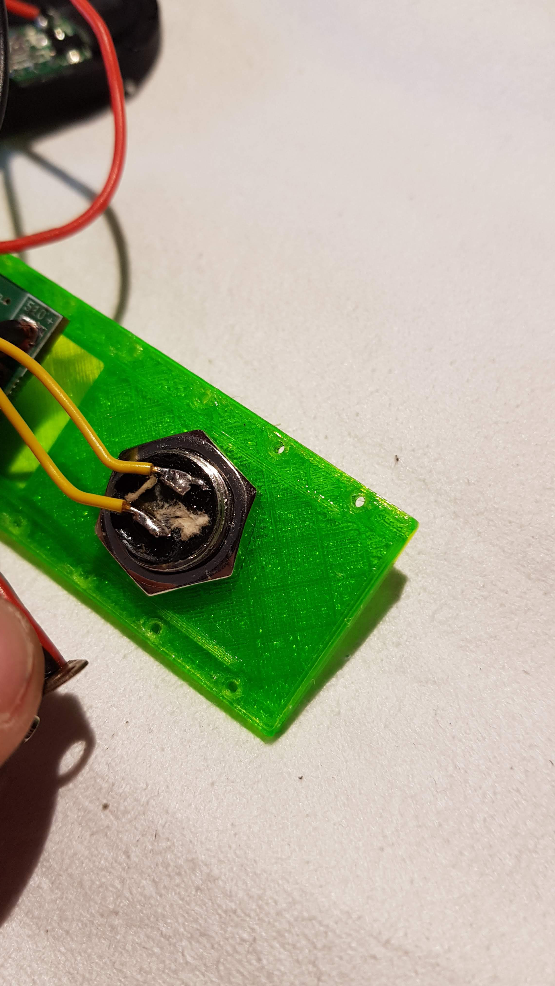
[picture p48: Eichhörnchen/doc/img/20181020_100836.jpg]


Slide the battery contacts onto the contact port. Be sure that the cable will NEVER contact the 510, as it might short.
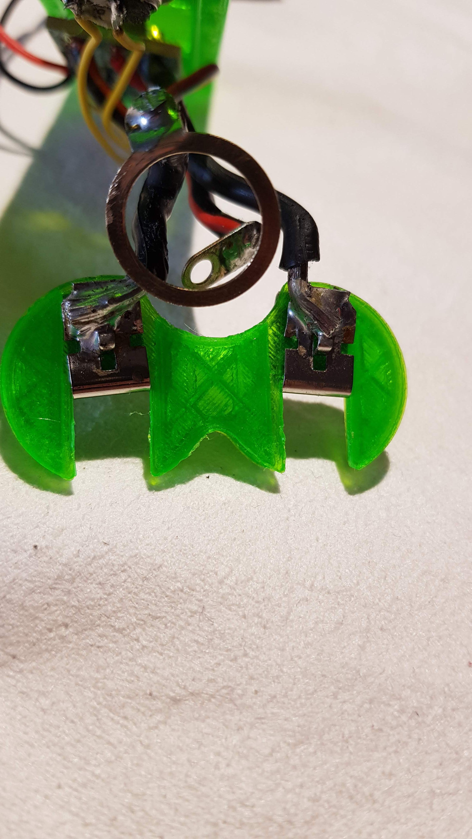
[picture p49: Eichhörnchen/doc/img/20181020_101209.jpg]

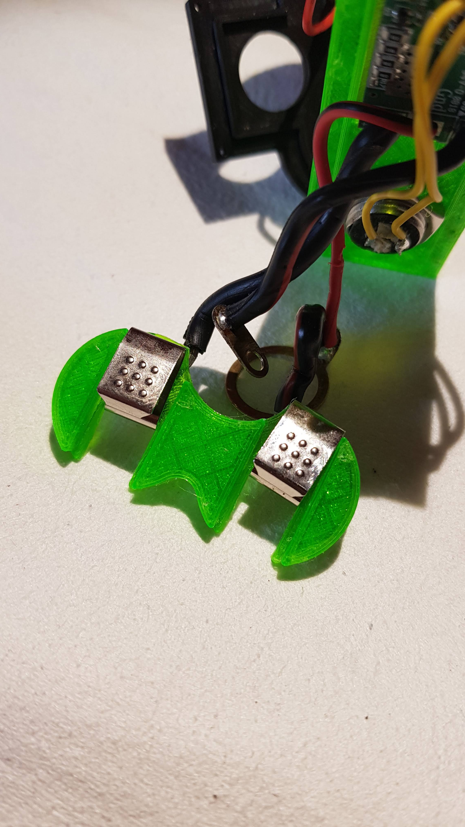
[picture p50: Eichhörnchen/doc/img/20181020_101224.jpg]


Assemble the 510
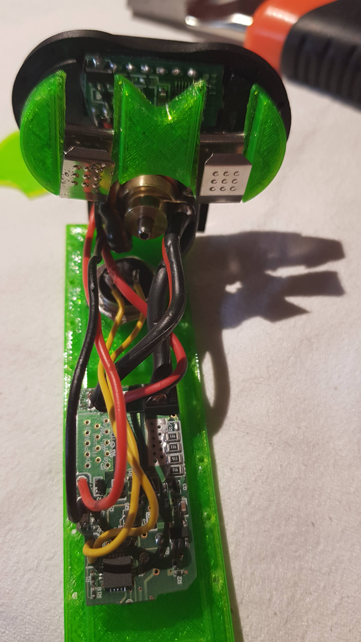
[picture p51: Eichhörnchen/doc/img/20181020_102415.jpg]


Put the insulator plate between the top and the top contact port, so that the cables cant touch the vm.
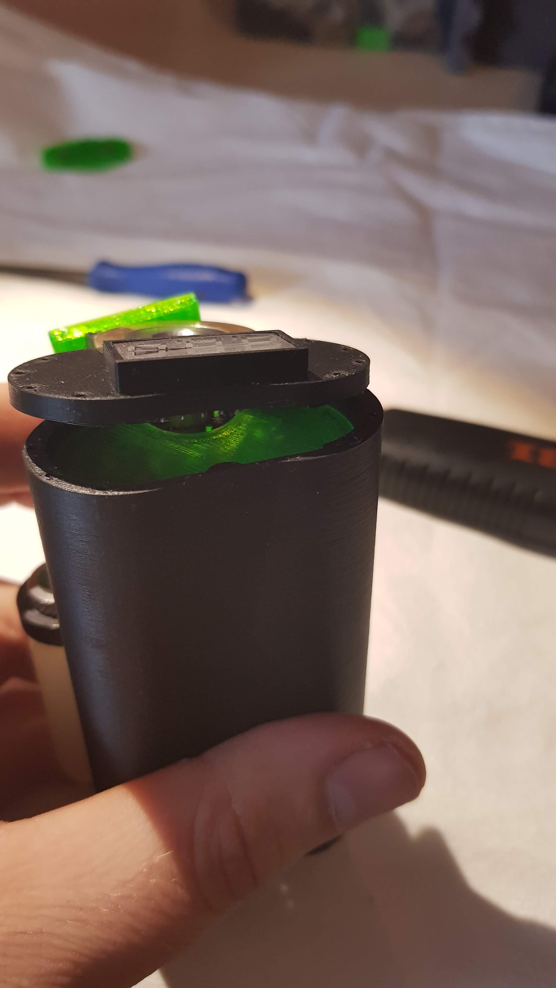
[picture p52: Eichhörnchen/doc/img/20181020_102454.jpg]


Carefully push in the top into the body.You might need to bend some wires. 
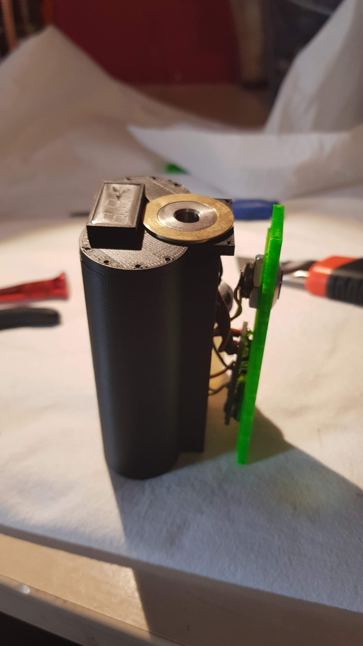
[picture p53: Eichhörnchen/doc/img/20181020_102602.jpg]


Pull the tube for your sounk bottle through the hole in the side and connect it to the 510.
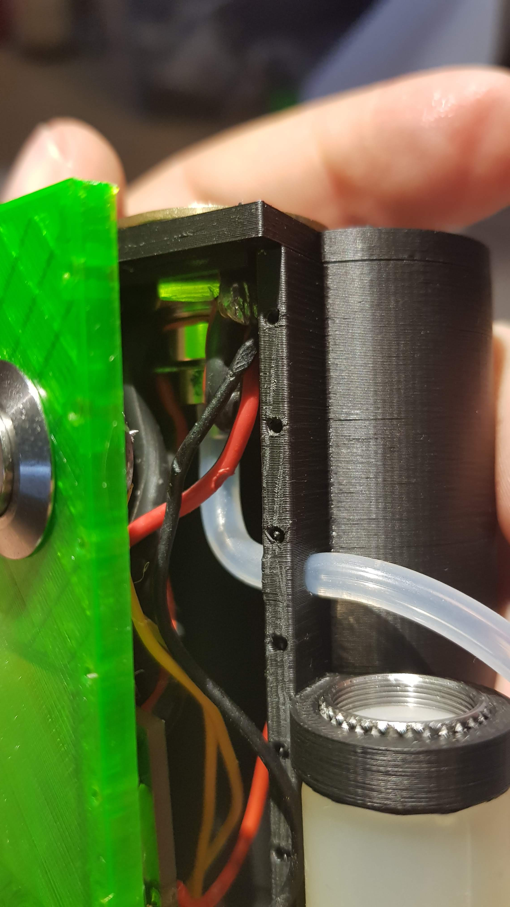
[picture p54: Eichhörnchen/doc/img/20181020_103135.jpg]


Carefully push in the front part into the body.It has to fit without any preasure and there shouldn't be any gaps. Otherwise check your wiring.
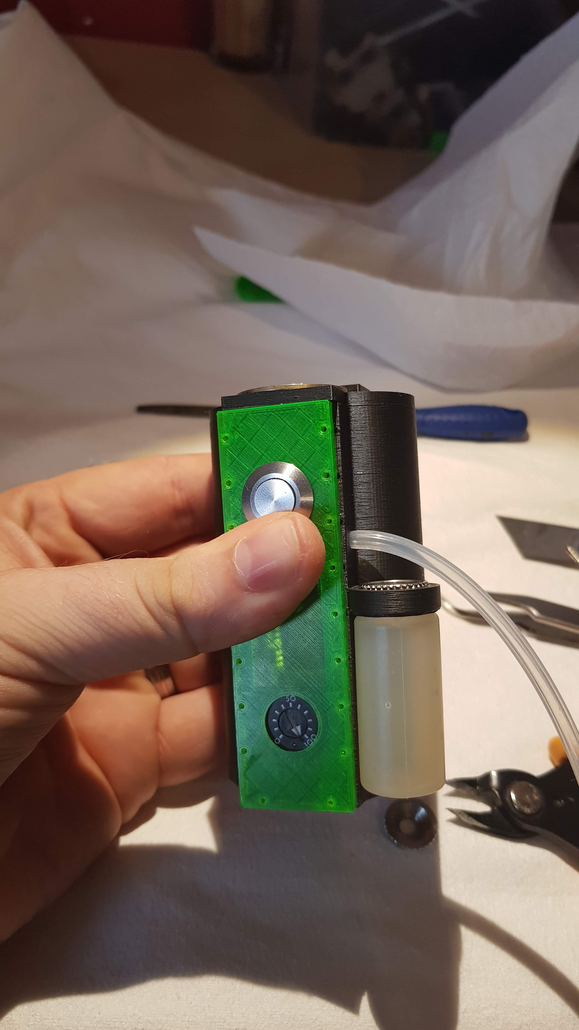
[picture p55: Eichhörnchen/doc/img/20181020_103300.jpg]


Put the screws in. While screwing, apply some preasure to make sure the parts fit together tightly. If you see a gap, reverse the screw and screw it in again while applying more preasure. Don't overtighten the screws.
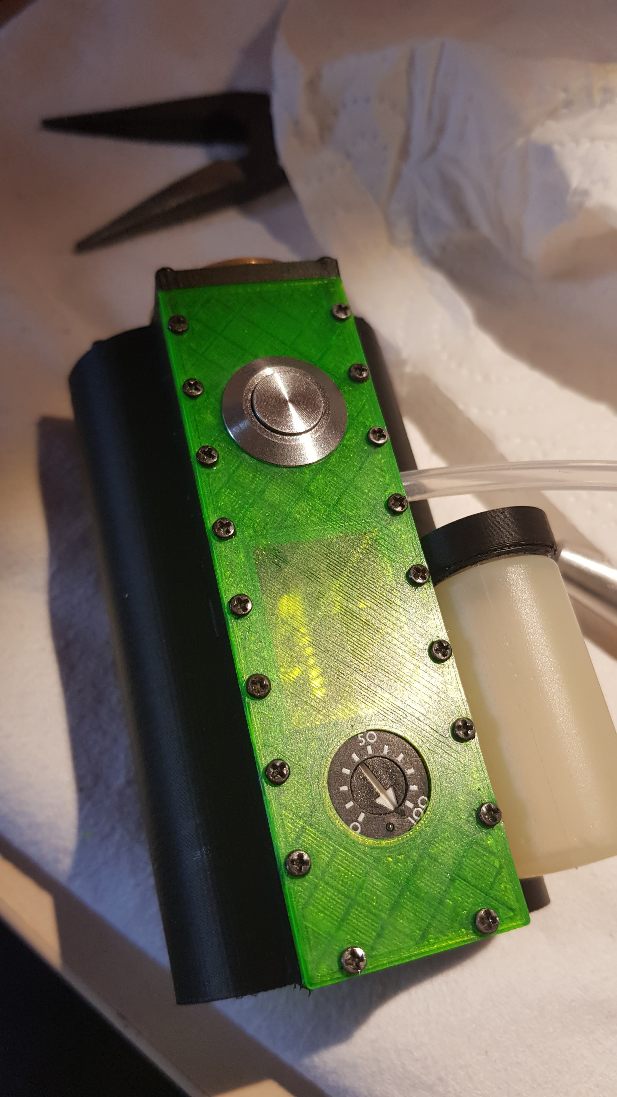
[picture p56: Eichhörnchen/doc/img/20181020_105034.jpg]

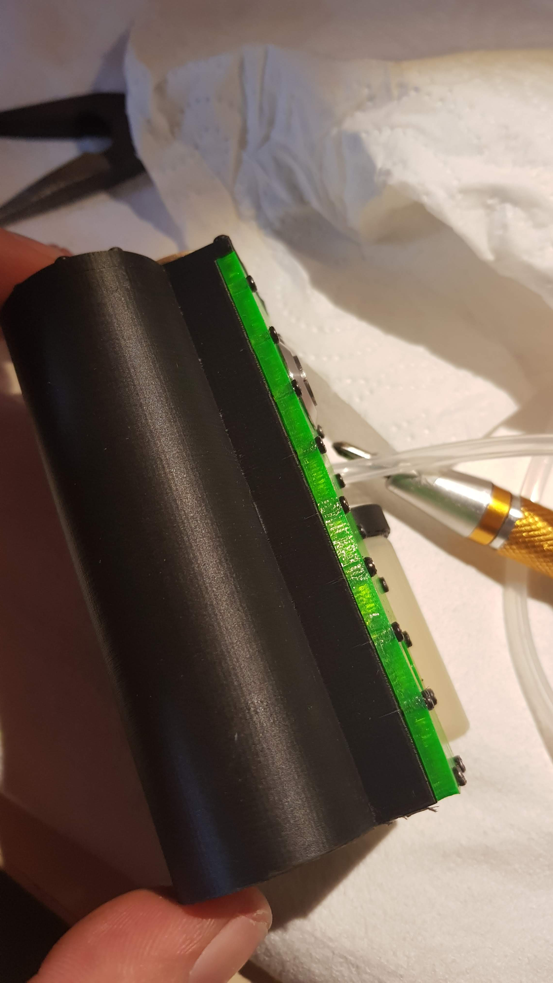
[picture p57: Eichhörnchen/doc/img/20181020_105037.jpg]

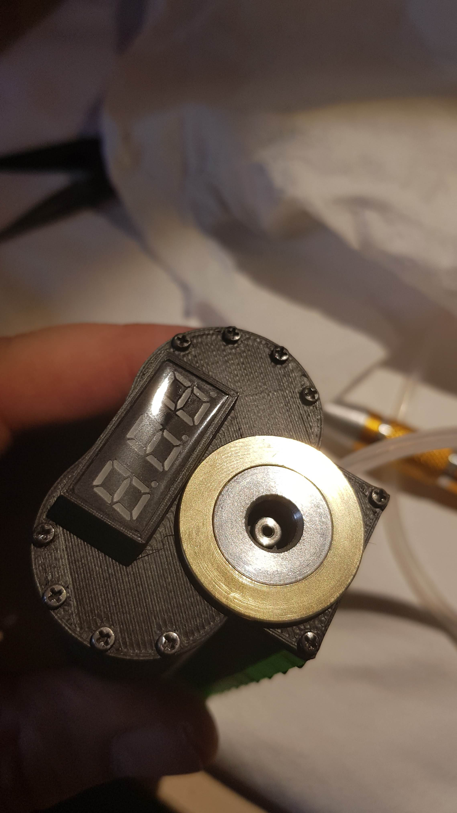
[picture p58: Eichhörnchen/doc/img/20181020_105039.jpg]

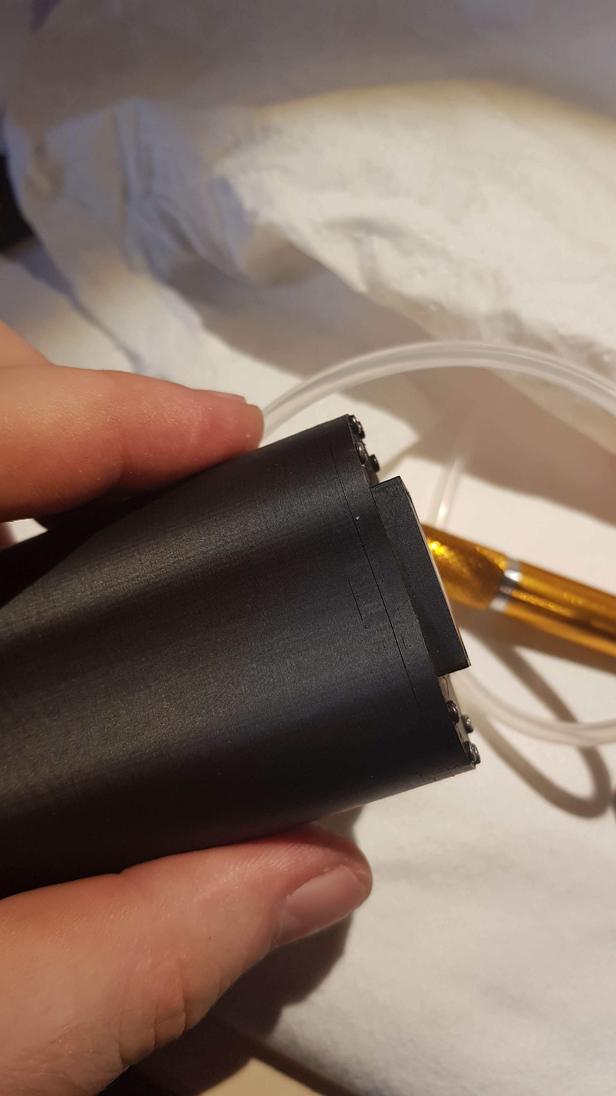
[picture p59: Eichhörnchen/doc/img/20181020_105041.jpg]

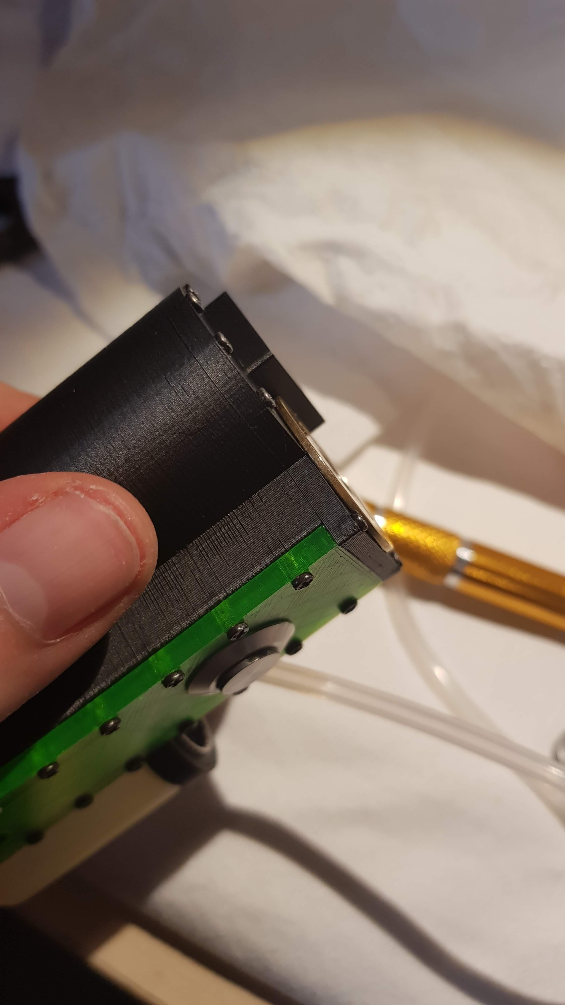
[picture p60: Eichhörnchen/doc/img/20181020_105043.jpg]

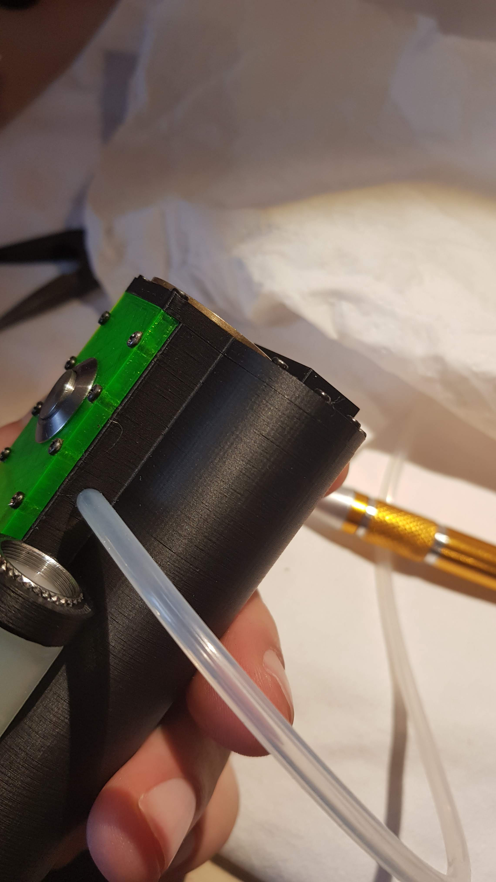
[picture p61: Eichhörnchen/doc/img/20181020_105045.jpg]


Cut the tube for the squonk bottle to length and put it into the bottle.
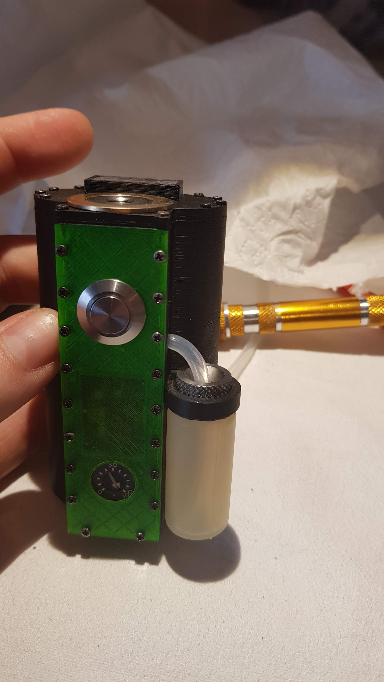
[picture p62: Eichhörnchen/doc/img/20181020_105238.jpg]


Put the batteries in carefully and test if everything is wired correctly. I usually put the batteries in and first use some pliers to test if the board is working correctly before firmly attaching the battery door. By doing this I am able to quickly pull back if something goes wrong.
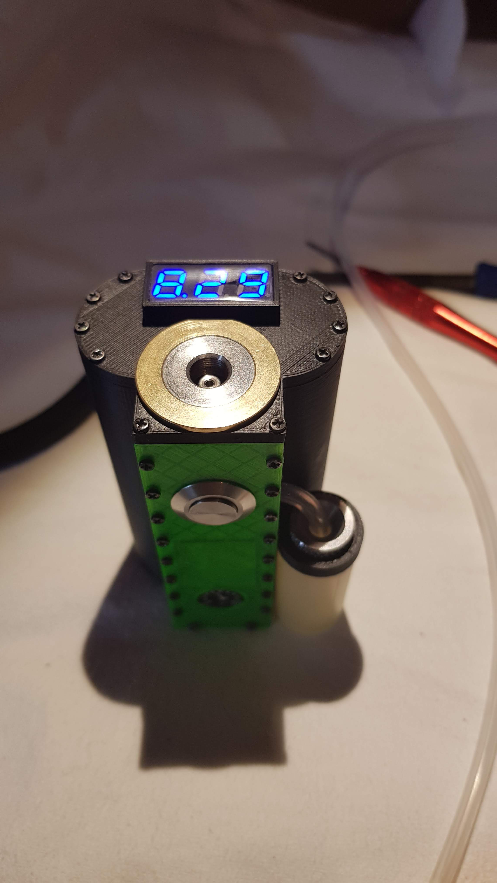
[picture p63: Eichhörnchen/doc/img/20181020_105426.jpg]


Your Mod is finished
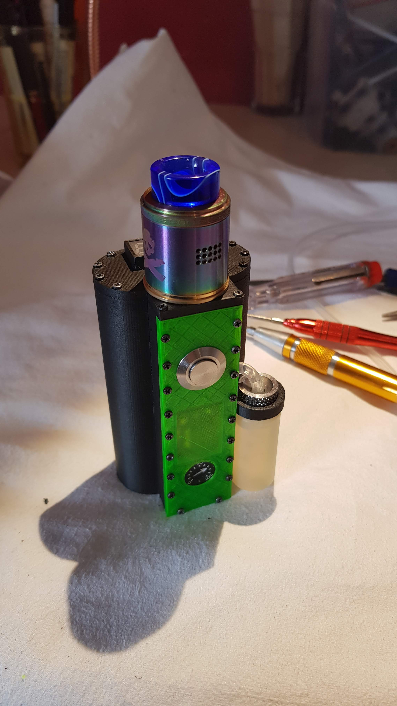
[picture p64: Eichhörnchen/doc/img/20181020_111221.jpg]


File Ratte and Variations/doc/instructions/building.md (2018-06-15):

# Building Ratte / Wisent / Leviathan

## Chosing the Model
I highly recommend to build "Die Ratte" first. "Die Ratte" is build many times by me and I'm vaping it for months daily. "Der Leviathan"
and "Der Wisent" are just interesting side projects and still need some work (although the do vape, but they are not perfect).

## Checking the printed parts
Before you start any soldering, you should check the printed parts. Many printers suffer dimensional inaccuracy. Start with measuring. Then start sticking the parts together, check the gaps.
The bottom door needs to slide firmly into the body. It should't be loose, but it also shouldn't require much force to slide it in. If you use too much force, you might break the body.
If the part fits too tight, you can use a knife to scrape off acess material.
If you want you can put in the screws to check if everything looks as expected.
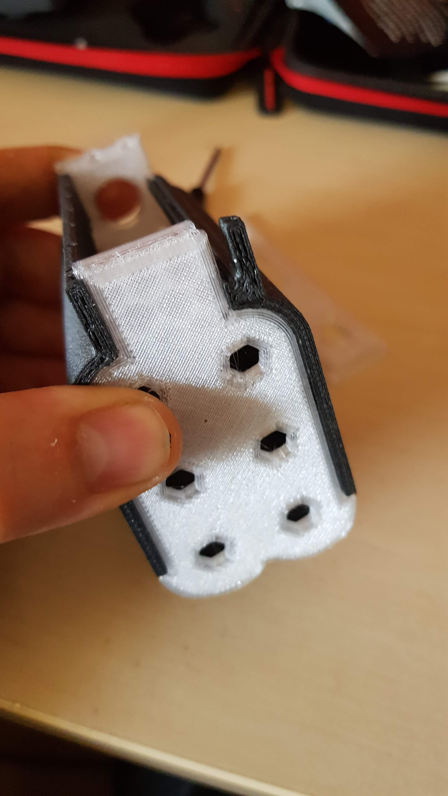
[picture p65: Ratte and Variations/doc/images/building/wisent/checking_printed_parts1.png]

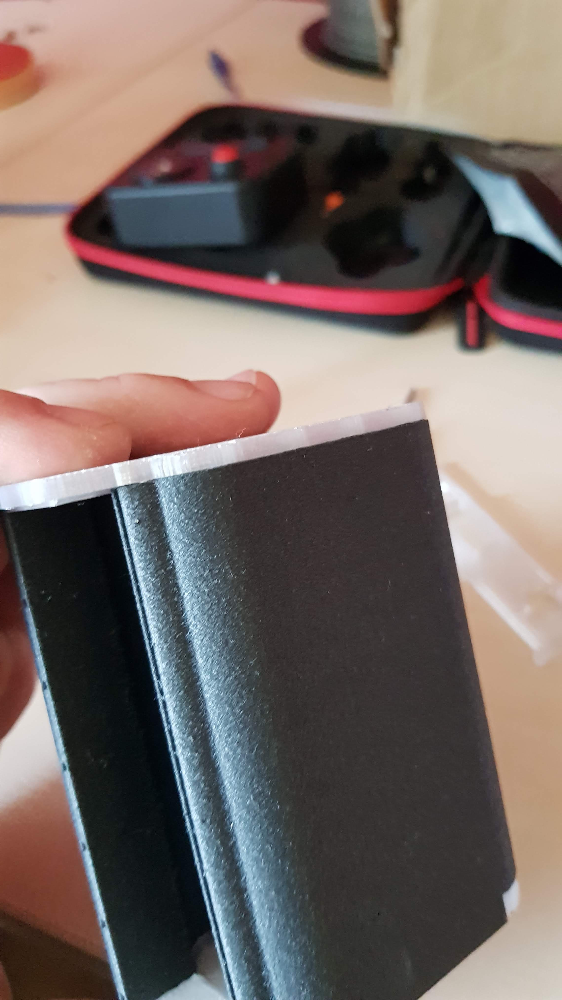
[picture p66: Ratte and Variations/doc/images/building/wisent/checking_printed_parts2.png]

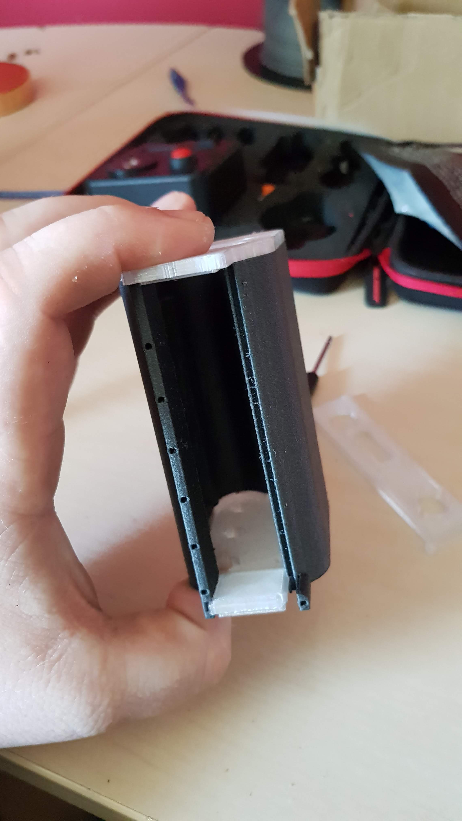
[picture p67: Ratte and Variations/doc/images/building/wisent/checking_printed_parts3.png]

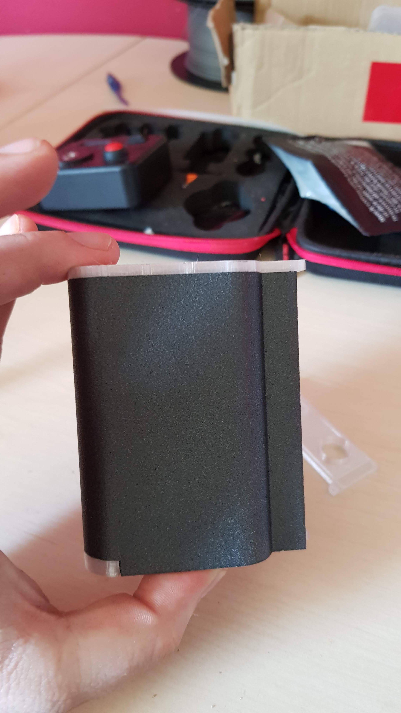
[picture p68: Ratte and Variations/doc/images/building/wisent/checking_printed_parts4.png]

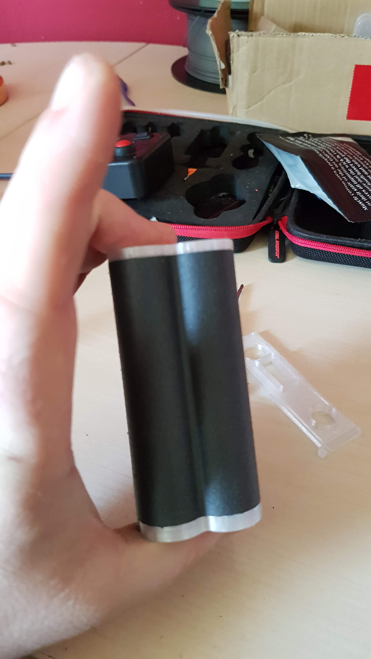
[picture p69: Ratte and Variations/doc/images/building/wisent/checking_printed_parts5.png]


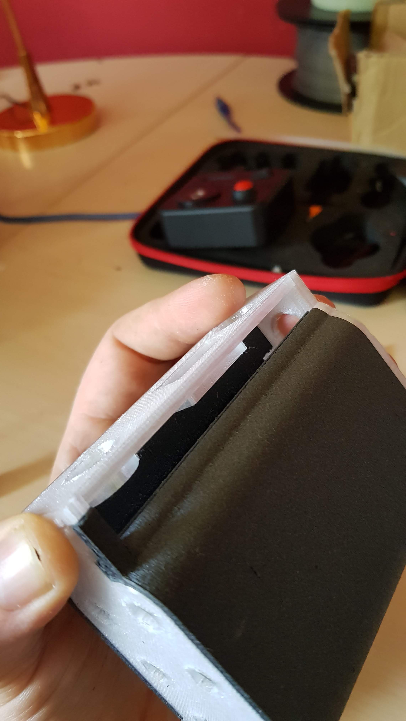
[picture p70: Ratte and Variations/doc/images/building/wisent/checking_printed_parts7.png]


## Manufacturing the contact plates
First we need 2 terminals where the cables coming from the board and the 510 are
beeing soldered to.
Cut a small piece of brass and drill a 3.2mm hole in it. The terminal doesnt need
to be bigger than the M3 nut. On one side, leave some space for the cable as
seen in the picture.


Next thing we need are bridges. For a dual 18650 you need one, for 4x18650 you
need 3 and for 6x18650 you need 5.
Drill 2 3.2mm holes into a brass plate. They must be 19mm apart. Then cut out the
plate. It doesn't need to be wider than the M3 nut.




## Electronics
In this example we use an iPWM board:
[iPWM Wire Diagram](https://github.com/johannes-otto/Librecig/blob/master/Ratte%20and%20Variations/doc/images/wire%20diagrams/iPWM%20Wiring%20Diagram.jpg)

If you got the another front plate and the components, you may use one of these diagrams:
- [ANT Wire Diagram](https://github.com/johannes-otto/Librecig/blob/master/Ratte%20and%20Variations/doc/images/wire%20diagrams/ANT%20PWM%20Wring%20Diagram.jpg)
- [Mosfet Wire Diagram]()

In any case. I use to cut the contacts of the button to save space. I usually leave about a mm. Also I cut the mount holes of the voltmeter. Be sure to have the button screwed in tightly. Bad things happen if the nut becomes loose an starts traveling inside your mod.
Don't glue in the components yet. I recommend not doing that before you verified that your soldering works.







## Connecting the Battery contacs
Solder the wires from the board and the 510 directly to the pole contacts.
You need a powerful soldering iron to get enough heat into the brass.


## Screwing in the 510
Use the 510 tightening tool to tighten the 510. Tighten it firmly to avoid
the 510 becoming loose while screwing/unscrewing the atomizer.



## Pre flight check
Use a pliers or something metallic to bridge the first two batteries.
You should see the mod turn on. If something strange happens, instantly pull away
the pliers.
If everything is working as it should, you can glue in the voltmeter and the pot now. I recommend just using a few drops of superglue. If you use too much, disassembling would be a pain.


## Optional: Preparing the squonk plate
Press the cap of the squonk bottle into the hole from the squonk plate. Don't press
it in too far, since the bottle wouldn't be sealed when not beeing screwed in far
enough. Leave the tube a bit longer. Now cut the tube on the bottom in the
bottle. Leave some 1mm space between the end of the tube and the bottom of The
bottle to let the liquid flow during the squonk action.





## Final Assembly
[image tightened top]()
Tighten the screws of the top part.

Optional: Insert the squonk plate
Now take some pliers again. Angled pliers are suited best for this part. Cut
the top part of the tube to length. and push the tube over the pin of the 510.
Don't leave the tube too long as it might block the liquid flow. Leave the bottle hanging to
the side of the mod.
While screwing in the screws of the front plate, you carefully hold the part in
Place.
After you put in a few screws, test if the connection is tight and the flow isn't blocked.
To do that, you can unscrew the bottle and carefully blow through the tube.

Put in some insulation between the switch and the 510
Now screw in the rest of the screws. Don't overtighten them. You are dealing with
plastics.



## Final check
Before you push in the battery door, check the function of the board again
with the pliers test we did earlier.


## Insert Batteries
When inserting the batteries, know your polarity. If you use the wisent, be sure to have the battery screws loose before inserting or removing the battery door. Otherwise you WILL short 4 batteries at the same time while the door jams!
Take your time when adjusting the contacts for the first time. You don't need much tension for the batteries to contact, but it's tricky on the wisent or the leviathan to get them all contact at the same time. If you overtighten the screws, you might break the mod.



## Done
Congrats. You're done. Be sure to look at the usage instructions.
[usage](https://github.com/johannes-otto/Librecig/blob/master/Ratte%20and%20Variations/doc/instructions/usage.md)





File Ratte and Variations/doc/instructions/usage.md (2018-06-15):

# Usage Instructions

## The Wisent is not safe
The Wisent is dangerous in any way. You shouldn't use it.

## Battery venting
As you might have noticed, the mods don't have any venting holes. This is ok for me, since the mods are not air tight.

## Mind your resistance
Building too low, especially on high voltage mods, may damage your batteries and may toast your electronics, too. BigAl's ANT board is
recommended for max 40A, the iPWM is recommended for 60A. You might check [bigalsmods](https://bigalsmods.com) for further information.
Anyway it's better to stay within the limits of your batteries. A good Sony VTC5A can deliver 30A.
For the minimum resistance, calculate with the fully charged voltage of your battery. The formula is:
number_of_batteries * 4.2 / max_battery_amps

Ratte:
2 * 4.2 / 30 = 0.28

Leviathan
4 * 4.2 / 30 = 0.56

Wisent
6 * 4.2 / 30 = 0.84

## Water
The mods are not waterproof. Using the mod in the rain for a few minutes was never a problem for me, but I wouldn't leave it in the rain.

## Refilling the squonk bottle
Just unscrew the bottle put your new juice in and screw it back on. It will leak a bit while the bottle is off, but I don't give a fk.

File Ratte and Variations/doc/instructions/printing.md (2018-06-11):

# Printing the parts

## Materials
The following Materials are recommended.

1. PETG

  + Easy to print
  + Mechanical durable
  + Available in many (translucent) Colors
  - Stringing
  
2. Carbonfill

  + Rough, matt surface
  + Mechanical Durable
  - Only black
  - Messy to print
  - Tends to clog nozzles
  - Need a hardened / plated nozzle
 
3. ABS / ASA

  + Mechanical durable
  + High temperature resistance
  + Available in many colors
  - Smells while printing
  - Harder to print
  - Need an enclusure to print
  
 PETG and Carbonfill resist about 80-100°C. This usually is enough, even for leaving the mod in the car during summer.
 ABS can withstand 100-120°C, but I wouldn't consider the worse printability worth it.

 ## Supports
 ### Body
 Support the overhangs and the slot for the battery door. You shouldn't put supports into the screw holes, as they are difficult to remove.
 
 
 
 ### Battery Cover
 The fit of the door is pretty tight. So it's recommended to support the overhang here.
 
 
 
 ### Squonk / Top Feed Plate
 Put some supports inside to support the top of the bottle holder. Don't use too many.
 
 

 [Back](https://github.com/johannes-otto/Librecig/blob/master/Ratte%20and%20Variations/Readme.md)

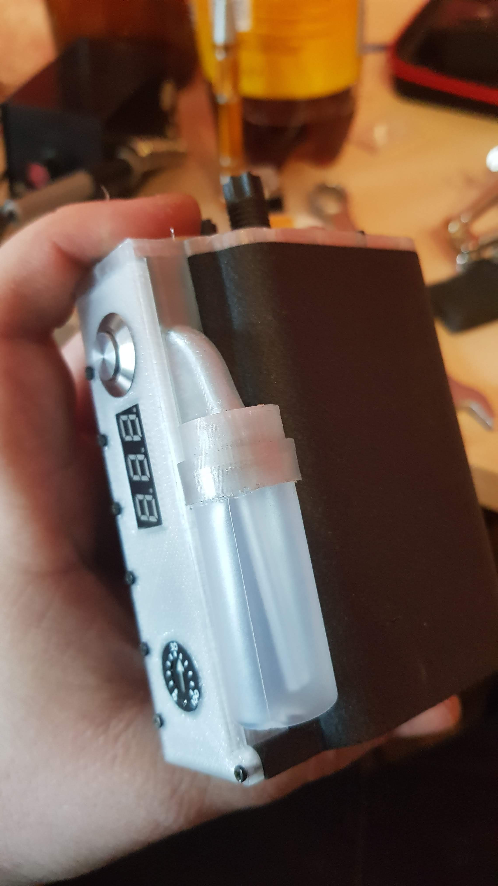
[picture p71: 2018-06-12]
Ratte and Variations/doc/images/building/wisent/assembly_done.png

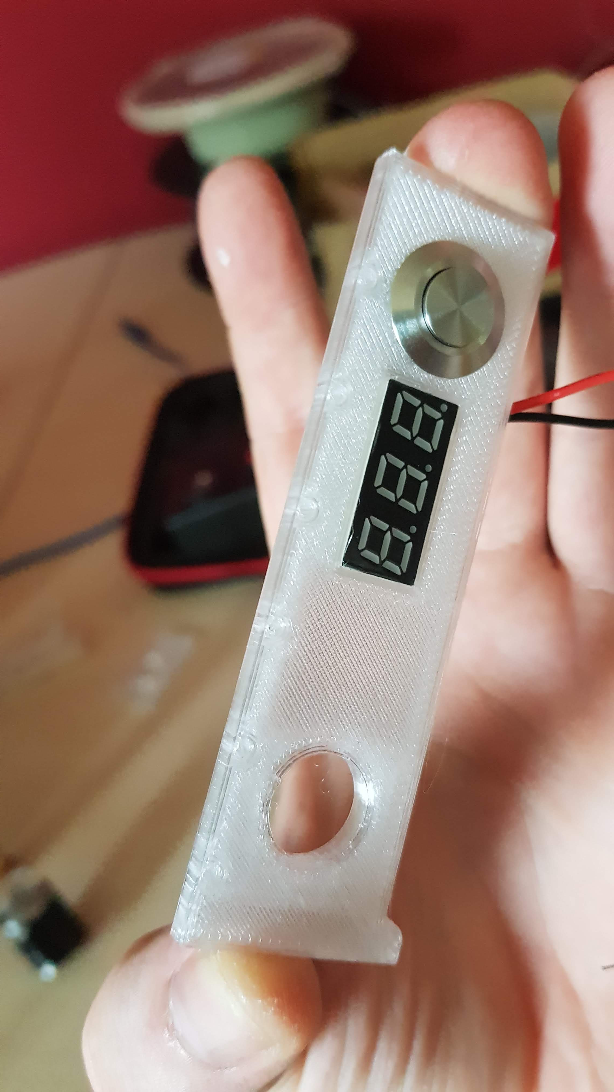
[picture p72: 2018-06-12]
Ratte and Variations/doc/images/building/wisent/new_front_plate_vm2.png

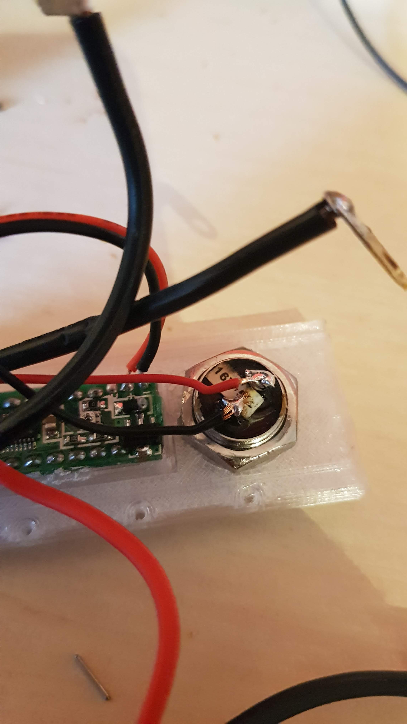
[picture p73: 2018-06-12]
Ratte and Variations/doc/images/building/wisent/soldering6.png

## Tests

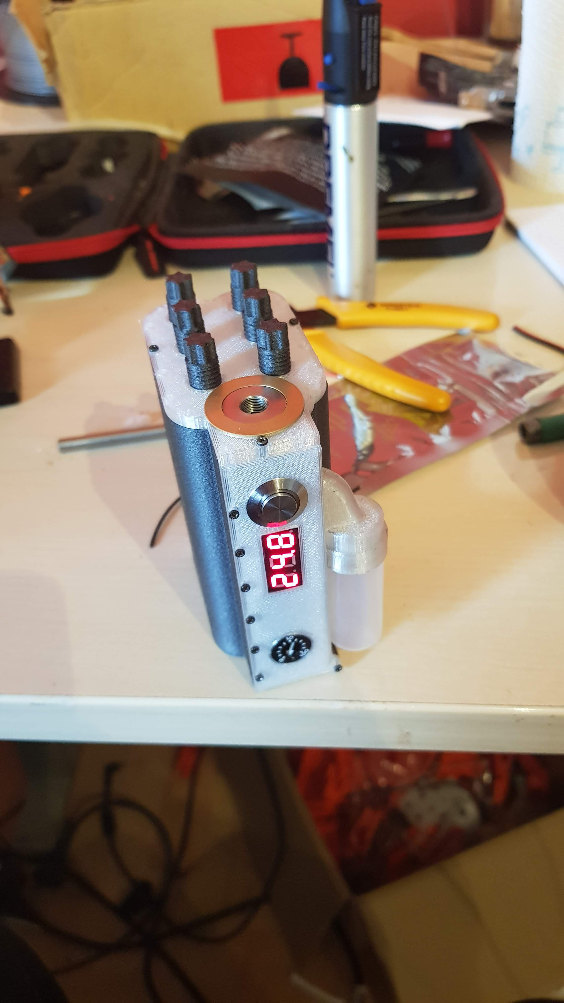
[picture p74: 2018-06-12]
Ratte and Variations/doc/images/building/wisent/final testing phase (4).png

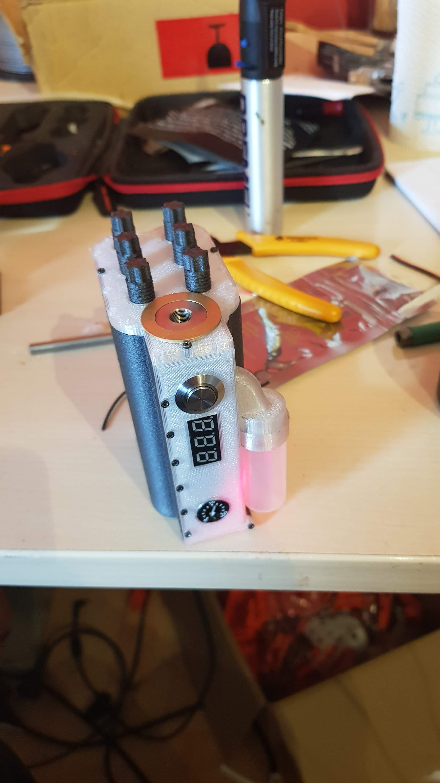
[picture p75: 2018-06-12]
Ratte and Variations/doc/images/building/wisent/final testing phase (1).png

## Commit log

2018-06-02 added parts for Leviathan
    [Leviathan Battery Cover.stl, Leviathan Body.stl, Leviathan Top Pole Cover.stl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]
2018-06-03 updated pole covers for wisent and leviathan
    [Leviathan Top Pole Cover.stl, Wisent Top Pole Cover 2.stl]
2018-06-10 new pictures
    [Long Screw for the drill.stl, Wisent Battery Door.stl, Wisent Body.stl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]
2018-06-15 added wire diagrams
    [Leviathan Battery Cover.stl, Leviathan Body.stl, Leviathan Top Pole Cover.stl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]
2018-06-19 updated parts for leviathan
    [Leviathan Battery Cover.stl, Leviathan Body.stl, Leviathan Top Pole Cover.stl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]
2018-10-05 added eichörnchen, updated parts of ratte
    [Ant Front.stl, Fat Screw.stl, Mosfet_Front.stl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]
2018-11-24 updated eichhörnchen, added non squonk version
    [battery door.stl, beautylip.stl, body.stl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]
2018-12-09 added Wiesel and Großwiesel, added Battery Compartments
    [22mm to 25mm adapter.stl, 25mm adapter.stl, Insert.stl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]
2018-12-22 new versions of wiesel, added wiesel v2 (pwm)
    [22mm to 25mm adapter.stl, Großwiesel v5_Großwiesel v5_22mm to 25mm adapter_Großwiesel v5.stl, Großwiesel v5_Großwiesel v5_battery door_Großwiesel v5.stl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]
2019-01-11 updated and merged wiesel, added otter
    [25mm adapter.stl, Otter v10.stl, Wiesel2 v4.stl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]
